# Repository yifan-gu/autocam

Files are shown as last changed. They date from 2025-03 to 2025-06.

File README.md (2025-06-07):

Arduino files for my auto-following camera car!

## TODO
- [x] Add dji remote control and receiver
- [x] <s>Add PID encoder</s> Add a web page for parameters
- [x] Add BLE central for the anchor
- [x] Read joystick values for the remote controller
- [x] Read mode switch button for remote controller
- [x] Add state indicator in the web UI
- [x] Add LED state indicators
- [x] Add battery state LED (tag, remote)
- [x] Add LED logic for tag
- [x] Add lock mode (remote)
- [x] Combine tag and remote
  - [x] Add tag selector (sensor, remote)
- [x] Control the BLE data rate
- [x] Fix UWB Anchor naming, fix AutocamController naming
- [x] Add PCB boards
  - [x] Sensor
  - [x] Verify LED resistor values
  - [x] Verify IO0/IO1 port on the ESP32 UWB is usable 
  - [x] Tag
  - [x] Server
  - [x] Remote
- [x] Smooth the distance measurement.
- [x] Added a different mode (follow).
- [x] Added gimbal recenter and camera recording.
- [x] Assemble together
- [x] Design and make the enclosure
- [ ] Calibrate the UWB tag and anchor
- [ ] Measure battery voltage.
- [ ] (optimize) Store settings in external storage (SD card)
- [x] (optimize) Refactor the server code with a state machine, (Almost a state machine now).
- [ ] (optimize) Refactor the sensor LED control with LED controller
- [ ] (optimize) Reorganize shared code into libraries, add external dependencies 

- [x] heartbeat for the remote controller.
- [ ] <s> Nice to have, detect active track failure</s> Turns out there's no API support for that
- [x] Smart Phone APP for the remote (BLE version).

## KNOWN ISSUES
- [ ] Webserver stabability.
- [x] Steering thread issue (Do not steer before throttle is applied)
- [x] BLE connection issue
- [ ] ESC init issue

<s>- [x] Start/stop recording issue</s> Not actually an issue—I plugged the USB-C cable into the wrong gimbal port. However, since the camera drains the gimbal’s battery, I still remove the cable to conserve power.

- [x] Every time the remote buttons are pressed, send values to the server.

## 🚗 Simulator

👉 [Run the Simulator](https://yifan-gu.github.io/autocam/simulator.html)

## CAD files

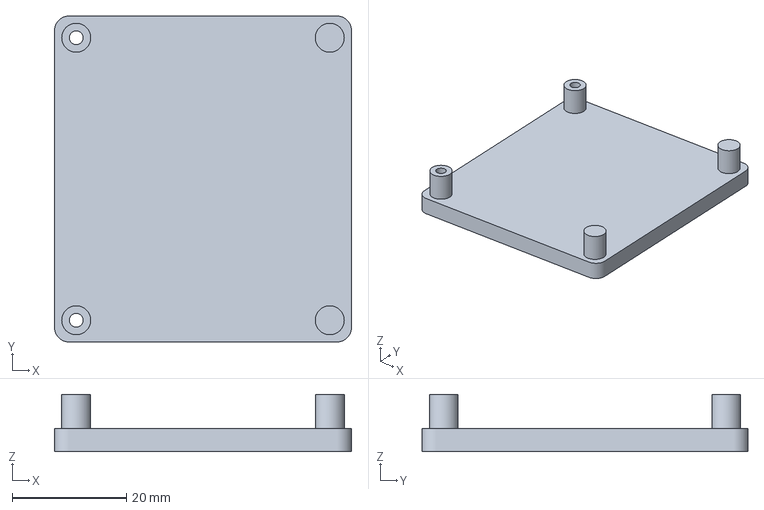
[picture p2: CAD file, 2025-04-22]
hardware/cad/server/Server Base-Base.3mf
52.1 x 57.1 x 10.0 mm

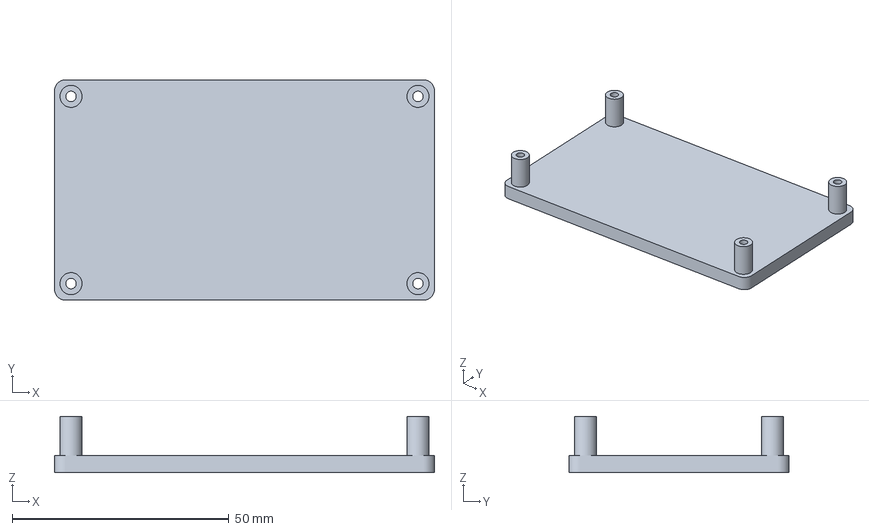
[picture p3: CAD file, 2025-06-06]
hardware/cad/tag/Tag Lid-Lid.3mf
87.6 x 50.8 x 13.0 mm

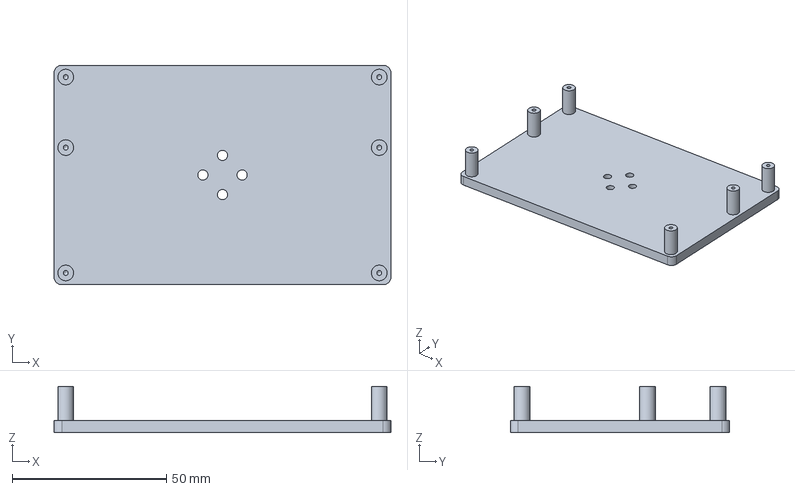
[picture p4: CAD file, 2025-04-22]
hardware/cad/remote/Remote Base.FCStd
109.2 x 71.1 x 15.0 mm

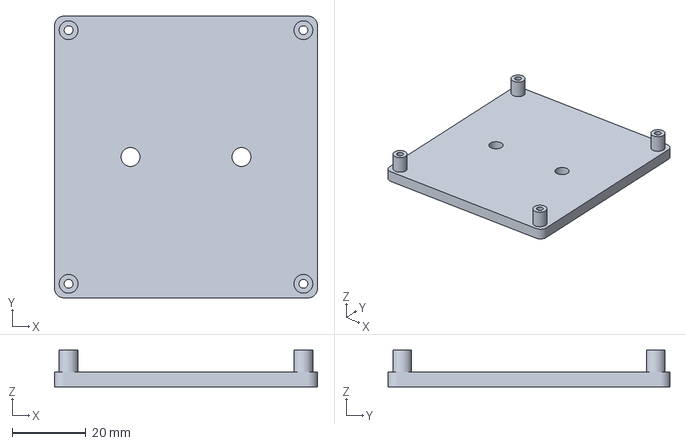
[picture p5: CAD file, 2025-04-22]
hardware/cad/sensor/Sensor Base-Base.3mf
71.1 x 76.2 x 10.0 mm

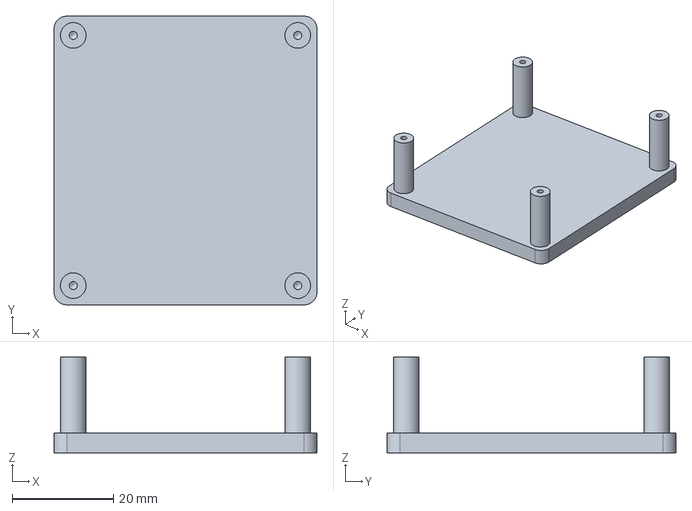
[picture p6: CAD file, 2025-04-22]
hardware/cad/server/Server Lid.FCStd
52.1 x 57.1 x 19.0 mm

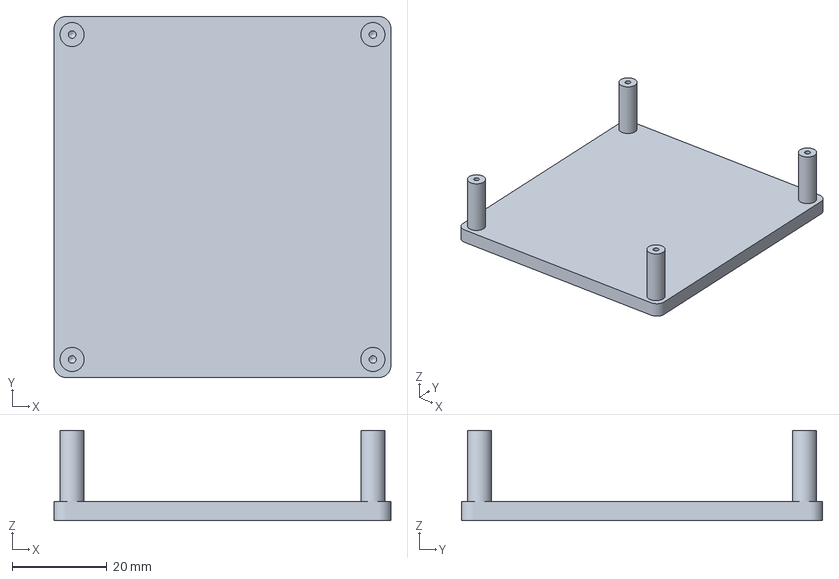
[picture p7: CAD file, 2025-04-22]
hardware/cad/sensor/Sensor Lid-Lid.3mf
71.1 x 76.2 x 19.0 mm

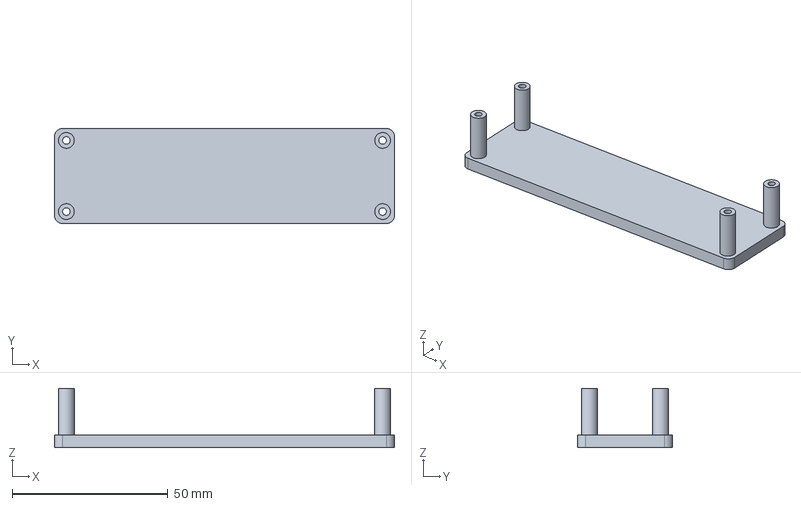
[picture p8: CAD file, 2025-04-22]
hardware/cad/remote/Remote Lid.FCStd
109.2 x 30.5 x 19.0 mm

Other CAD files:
hardware/cad/remote/Remote Assembly.FCStd
hardware/cad/sensor/Sensor Assembly.FCStd
hardware/cad/tag/Tag Assembly.FCStd
hardware/cad/server/Server Assembly.FCStd
hardware/cad/tag/Tag Base.FCStd
hardware/cad/remote/Remote Base-Base.3mf
hardware/cad/server/Server Base.FCStd
hardware/cad/tag/Tag Lid.FCStd
hardware/cad/sensor/Sensor Base.FCStd
hardware/cad/server/Server Lid-Lid.3mf
hardware/cad/remote/Remote Lid-Lid.3mf
hardware/cad/sensor/Sensor Lid.FCStd
hardware/cad/tag/Tag Base-Base.3mf

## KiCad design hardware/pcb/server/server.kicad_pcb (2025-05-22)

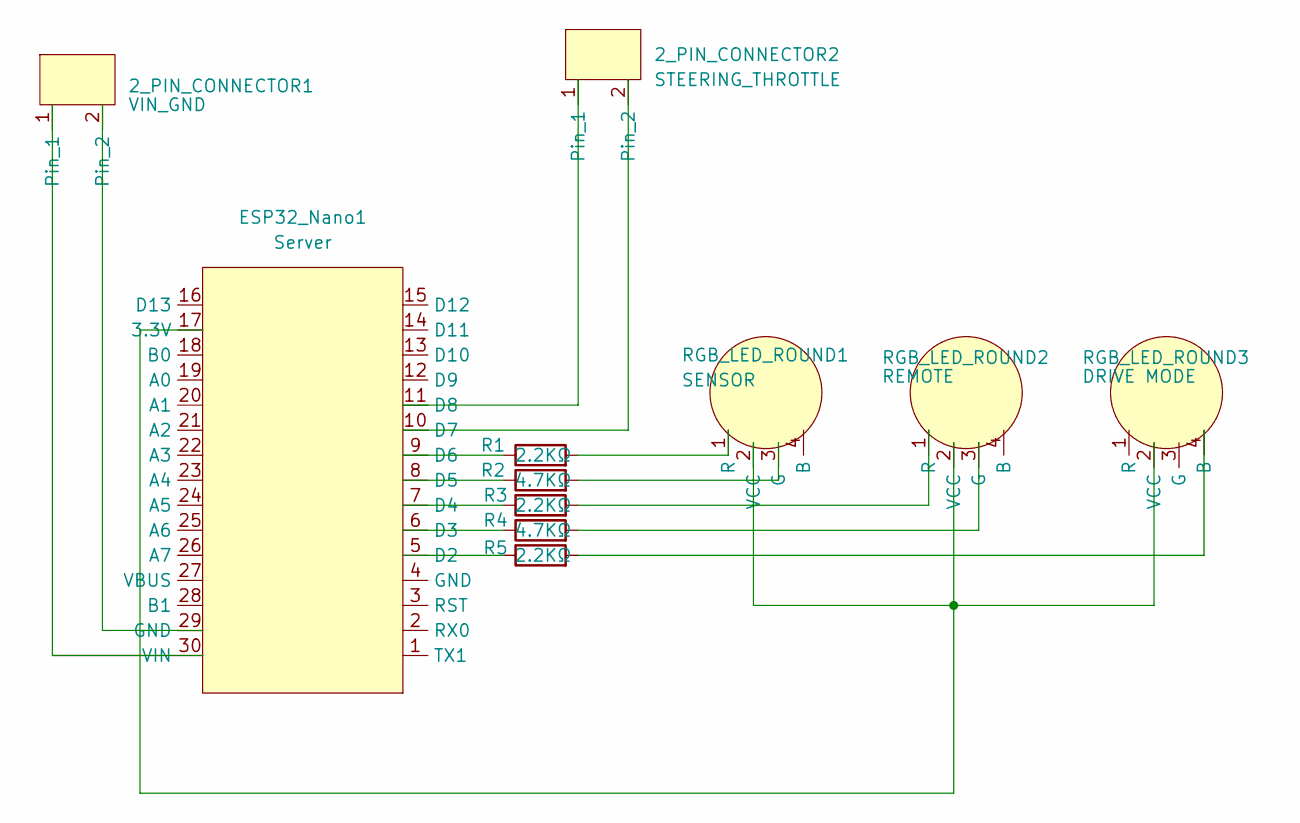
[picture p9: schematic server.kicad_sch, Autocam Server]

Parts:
2_PIN_CONNECTOR1: VIN_GND; 2-PIN Connector
2_PIN_CONNECTOR2: STEERING_THROTTLE; 2-PIN Connector
ESP32_Nano1: Server; Arduino ESP32 Nano
R1, R3, R5: 2.2KΩ; Simple Resistor
R2, R4: 4.7KΩ; Simple Resistor
RGB_LED_ROUND1: SENSOR; Anode RGB LED (Round)
RGB_LED_ROUND2: REMOTE; Anode RGB LED (Round)
RGB_LED_ROUND3: DRIVE MODE; Anode RGB LED (Round)

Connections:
unnamed: 2_PIN_CONNECTOR1.1, ESP32_Nano1.30 (VIN)
unnamed: 2_PIN_CONNECTOR1.2, ESP32_Nano1.29 (GND)
unnamed: 2_PIN_CONNECTOR2.1, ESP32_Nano1.11 (D8)
unnamed: 2_PIN_CONNECTOR2.2, ESP32_Nano1.10 (D7)
unnamed: ESP32_Nano1.17 (3.3V), RGB_LED_ROUND1.2 (VCC), RGB_LED_ROUND2.2 (VCC), RGB_LED_ROUND3.2 (VCC)
unnamed: ESP32_Nano1.5 (D2), R5.1
unnamed: ESP32_Nano1.6 (D3), R4.1
unnamed: ESP32_Nano1.7 (D4), R3.1
unnamed: ESP32_Nano1.8 (D5), R2.1
unnamed: ESP32_Nano1.9 (D6), R1.1
unnamed: R2.2, RGB_LED_ROUND1.3 (G)
unnamed: R1.2, RGB_LED_ROUND1.1 (R)
unnamed: R4.2, RGB_LED_ROUND2.3 (G)
unnamed: R3.2, RGB_LED_ROUND2.1 (R)
unnamed: R5.2, RGB_LED_ROUND3.4 (B)

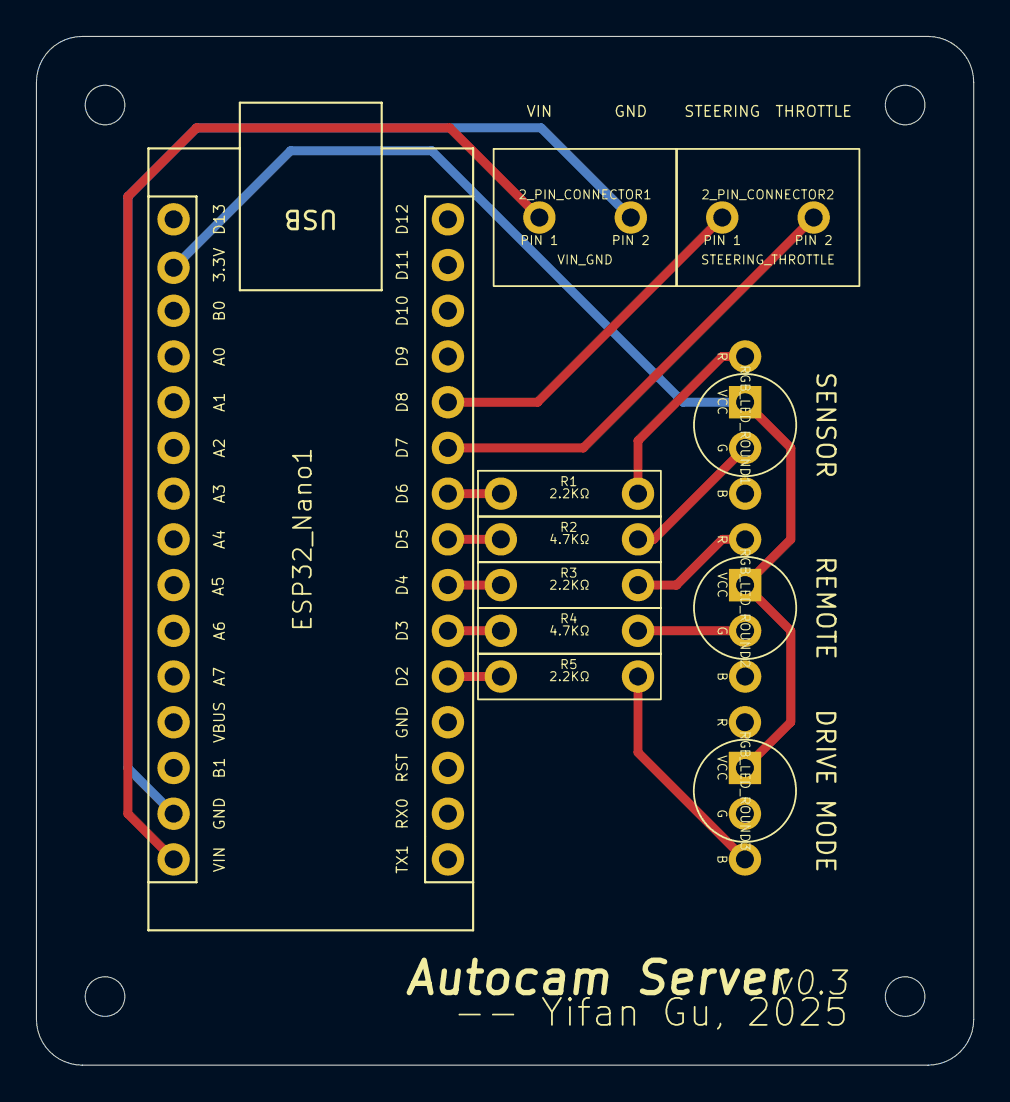
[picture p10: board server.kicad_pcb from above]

Board: 2 copper layers, 52.1 x 57.2 mm, 11 parts (0 on the bottom side), 15 nets.

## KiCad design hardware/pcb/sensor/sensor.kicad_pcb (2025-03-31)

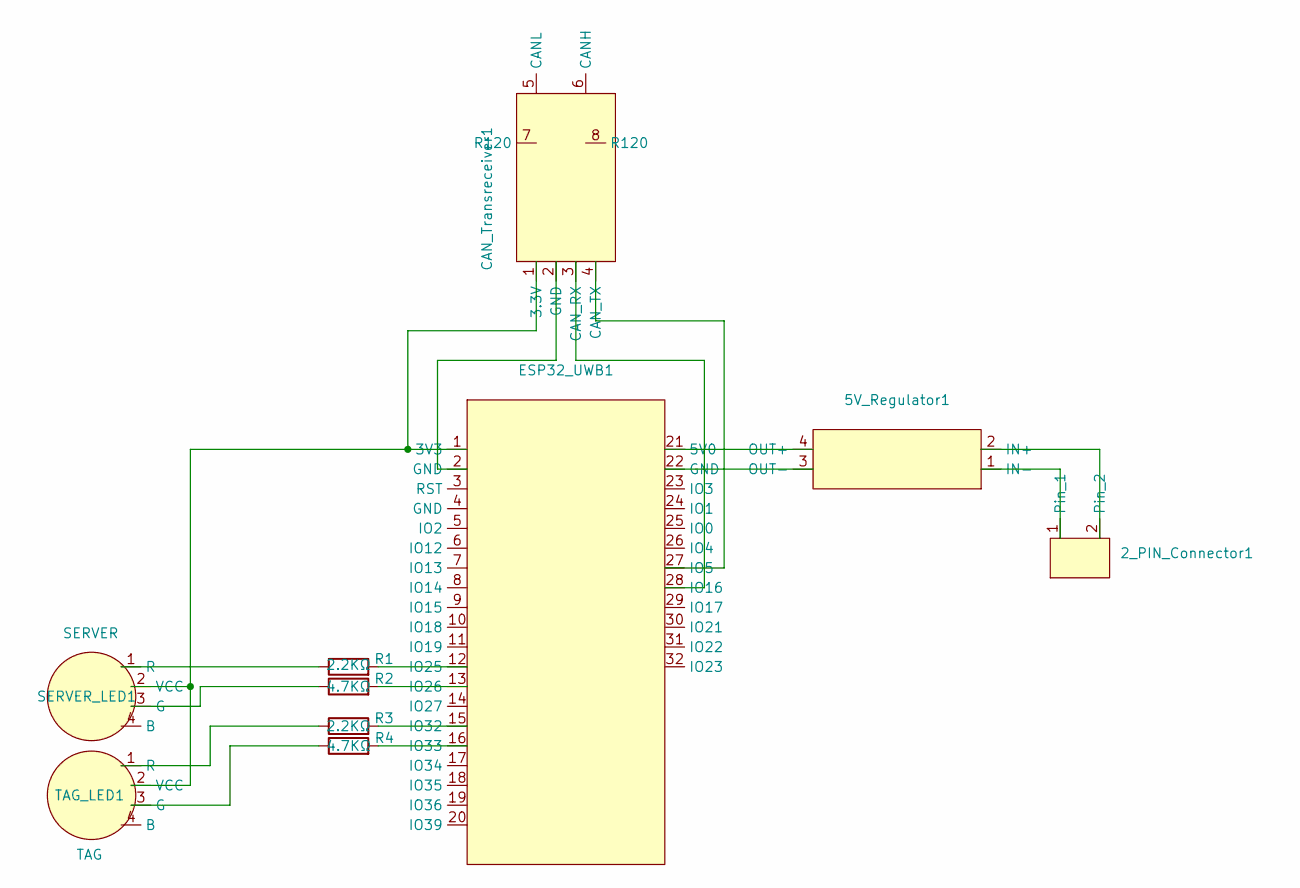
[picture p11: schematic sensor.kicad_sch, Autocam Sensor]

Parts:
2_PIN_Connector1: 2-PIN Connector
5V_Regulator1: MP1584EN 5V Regulator
CAN_Transreceiver1: Waveshare CAN Transreceiver
ESP32_UWB1: Makersfab ESP32 UWB
R1, R3: 2.2KΩ; Simple Resistor
R2, R4: 4.7KΩ; Simple Resistor
SERVER_LED1: SERVER; Anode RGB LED (Round)
TAG_LED1: TAG; Anode RGB LED (Round)

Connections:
unnamed: 2_PIN_Connector1.1, 5V_Regulator1.1 (IN-)
unnamed: 2_PIN_Connector1.2, 5V_Regulator1.2 (IN+)
unnamed: 5V_Regulator1.4 (OUT+), ESP32_UWB1.21 (5V0)
unnamed: 5V_Regulator1.3 (OUT-), ESP32_UWB1.22 (GND)
unnamed: CAN_Transreceiver1.1 (3.3V), ESP32_UWB1.1 (3V3), SERVER_LED1.2 (VCC), TAG_LED1.2 (VCC)
unnamed: CAN_Transreceiver1.3 (CAN_RX), ESP32_UWB1.28 (IO16)
unnamed: CAN_Transreceiver1.4 (CAN_TX), ESP32_UWB1.27 (IO5)
unnamed: CAN_Transreceiver1.2 (GND), ESP32_UWB1.2 (GND)
unnamed: ESP32_UWB1.12 (IO25), R1.2
unnamed: ESP32_UWB1.13 (IO26), R2.2
unnamed: ESP32_UWB1.15 (IO32), R3.2
unnamed: ESP32_UWB1.16 (IO33), R4.2
unnamed: R2.1, SERVER_LED1.3 (G)
unnamed: R1.1, SERVER_LED1.1 (R)
unnamed: R4.1, TAG_LED1.3 (G)
unnamed: R3.1, TAG_LED1.1 (R)

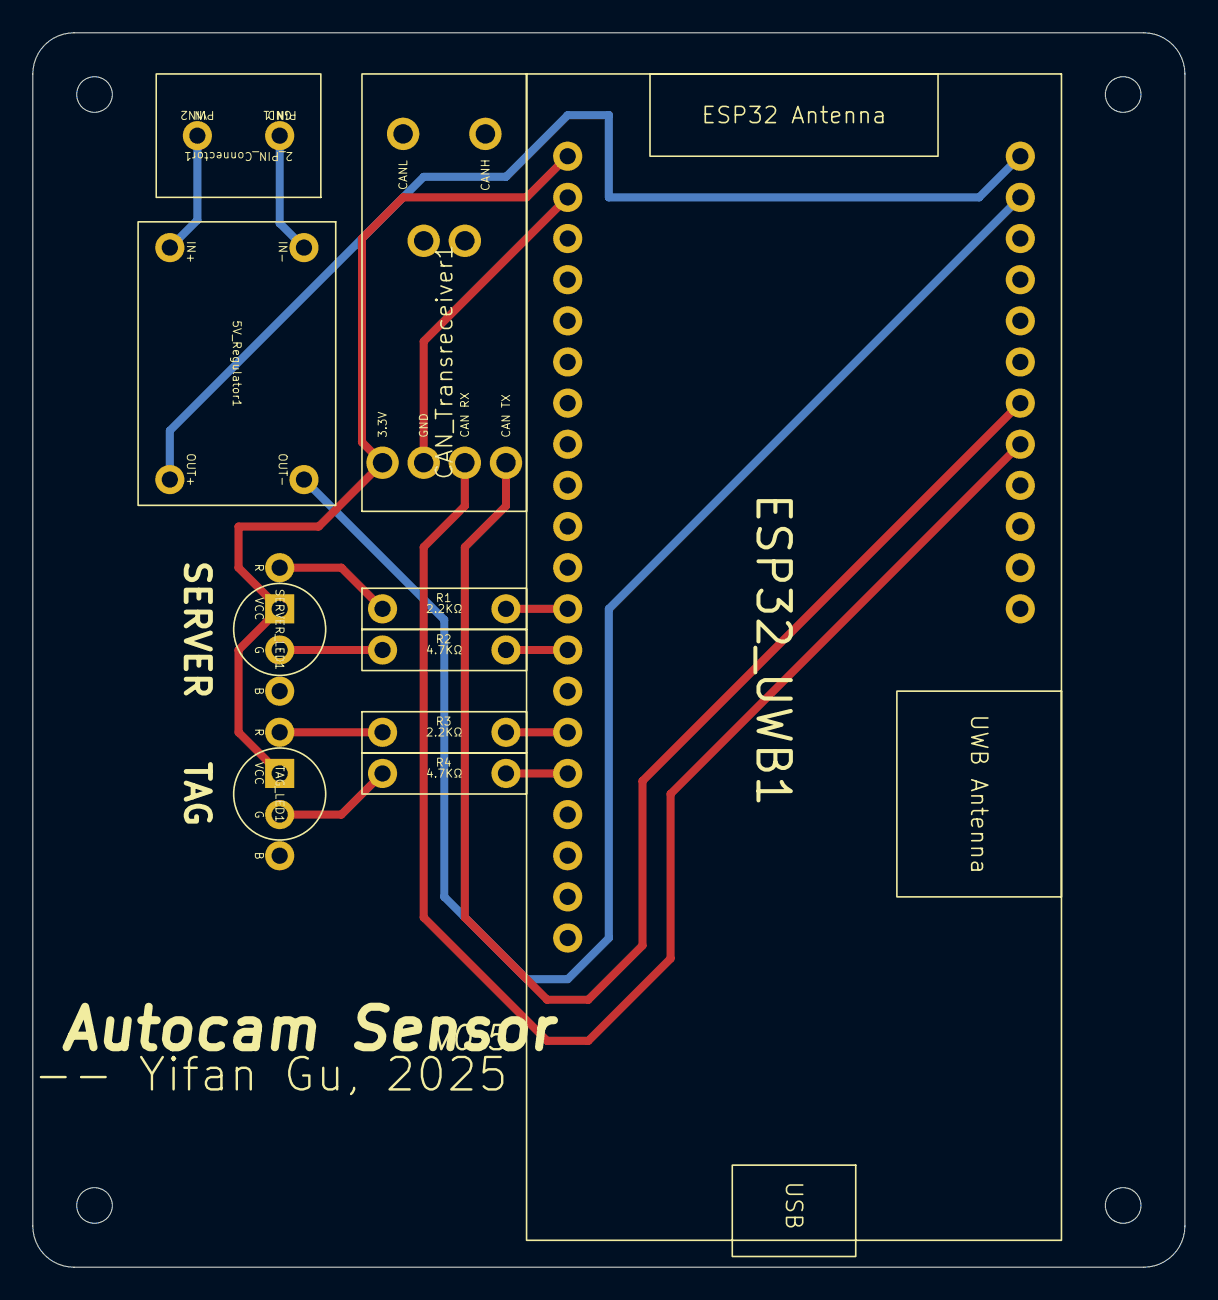
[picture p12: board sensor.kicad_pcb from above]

Board: 2 copper layers, 71.1 x 76.2 mm, 10 parts (0 on the bottom side), 16 nets.

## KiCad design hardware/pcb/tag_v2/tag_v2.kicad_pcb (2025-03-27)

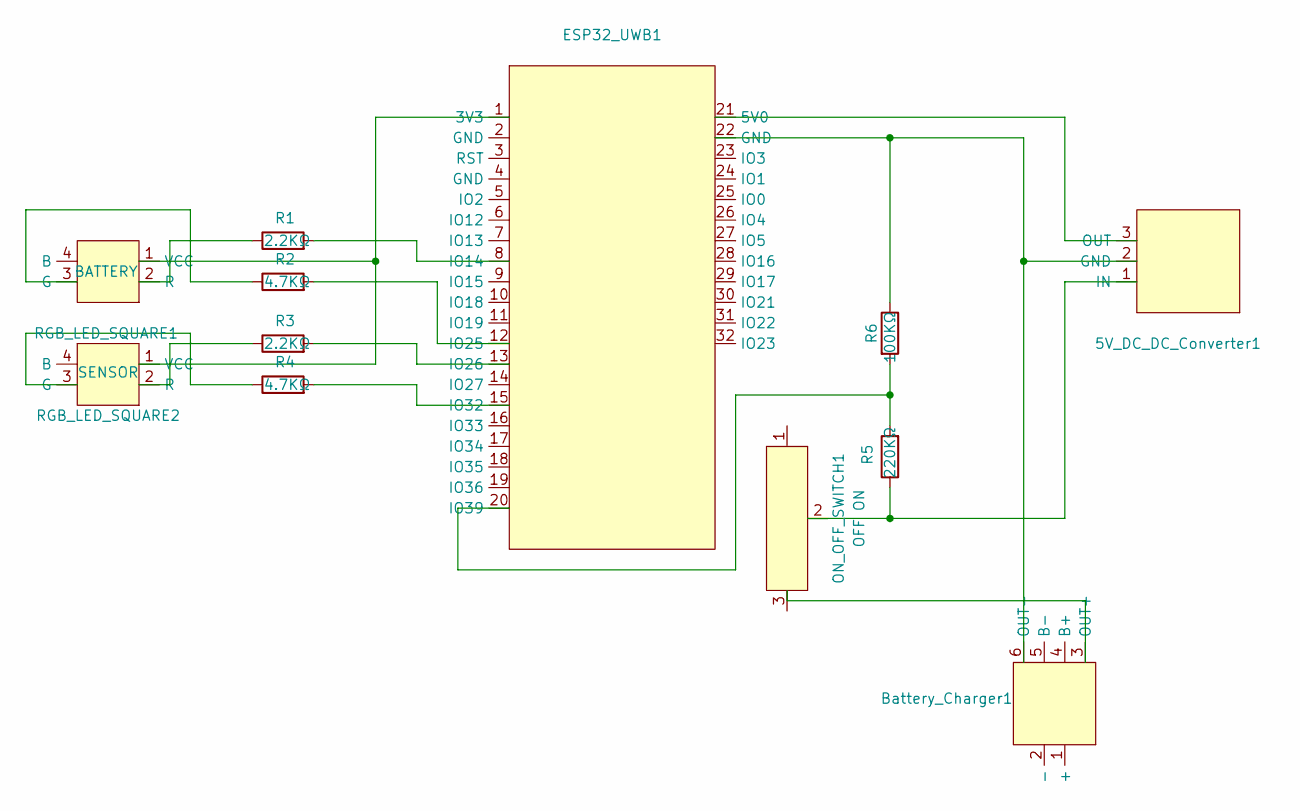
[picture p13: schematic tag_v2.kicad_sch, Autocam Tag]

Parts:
5V_DC_DC_Converter1: 5V DC-DC Step Up Converter (Square)
Battery_Charger1: USB-C 3.7V Lithium Battery Charger
ESP32_UWB1: Makersfab ESP32 UWB
ON_OFF_SWITCH1: OFF ON; 3-PIN Switch
R1, R3: 2.2KΩ; Simple Resistor
R2, R4: 4.7KΩ; Simple Resistor
R5: 220KΩ; Simple Resistor
R6: 100KΩ; Simple Resistor
RGB_LED_SQUARE1: BATTERY; Anode RGB LED (Square)
RGB_LED_SQUARE2: SENSOR; Anode RGB LED (Square)

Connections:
unnamed: 5V_DC_DC_Converter1.2 (GND), Battery_Charger1.6 (OUT-), ESP32_UWB1.22 (GND), R6.1
unnamed: 5V_DC_DC_Converter1.1 (IN), ON_OFF_SWITCH1.2, R5.1
unnamed: 5V_DC_DC_Converter1.3 (OUT), ESP32_UWB1.21 (5V0)
unnamed: Battery_Charger1.3 (OUT+), ON_OFF_SWITCH1.3
unnamed: ESP32_UWB1.1 (3V3), RGB_LED_SQUARE1.1 (VCC), RGB_LED_SQUARE2.1 (VCC)
unnamed: ESP32_UWB1.8 (IO14), R1.2
unnamed: ESP32_UWB1.12 (IO25), R2.2
unnamed: ESP32_UWB1.13 (IO26), R3.2
unnamed: ESP32_UWB1.15 (IO32), R4.2
unnamed: ESP32_UWB1.20 (IO39), R5.2, R6.2
unnamed: R2.1, RGB_LED_SQUARE1.3 (G)
unnamed: R1.1, RGB_LED_SQUARE1.2 (R)
unnamed: R4.1, RGB_LED_SQUARE2.3 (G)
unnamed: R3.1, RGB_LED_SQUARE2.2 (R)

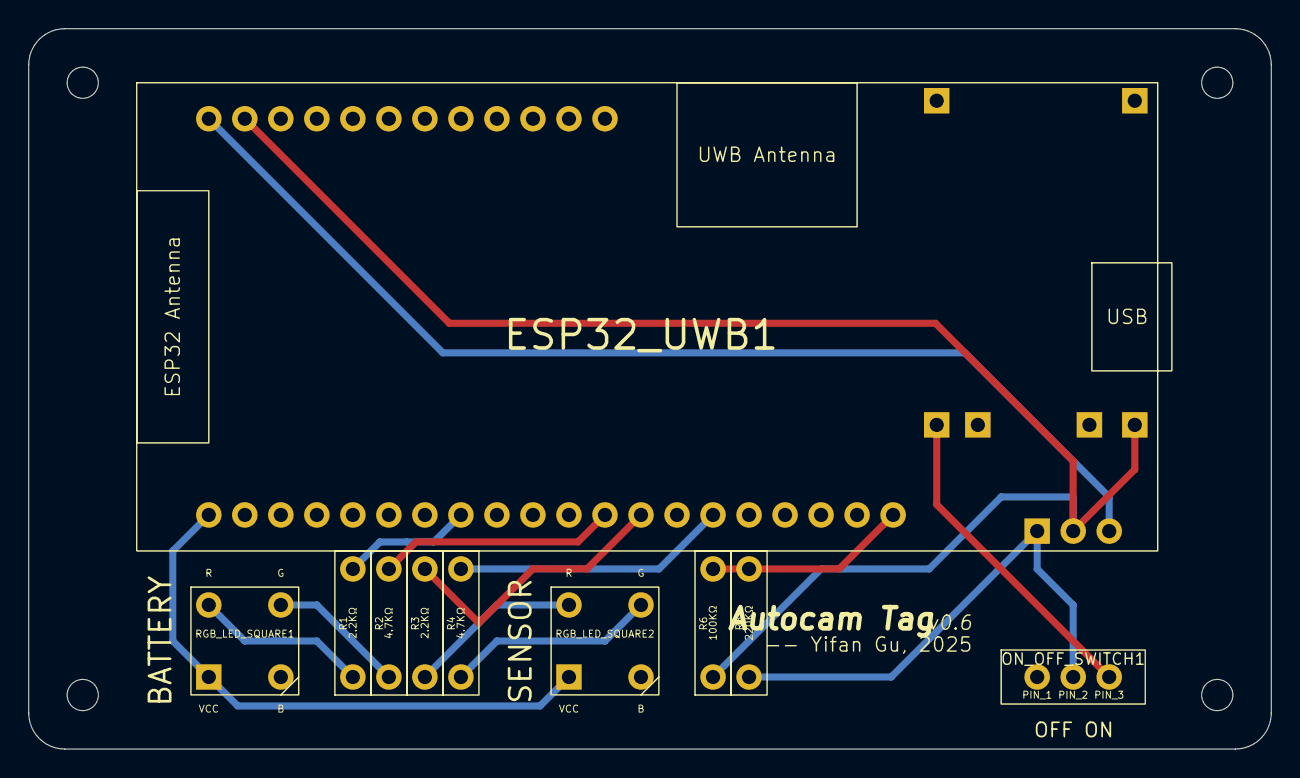
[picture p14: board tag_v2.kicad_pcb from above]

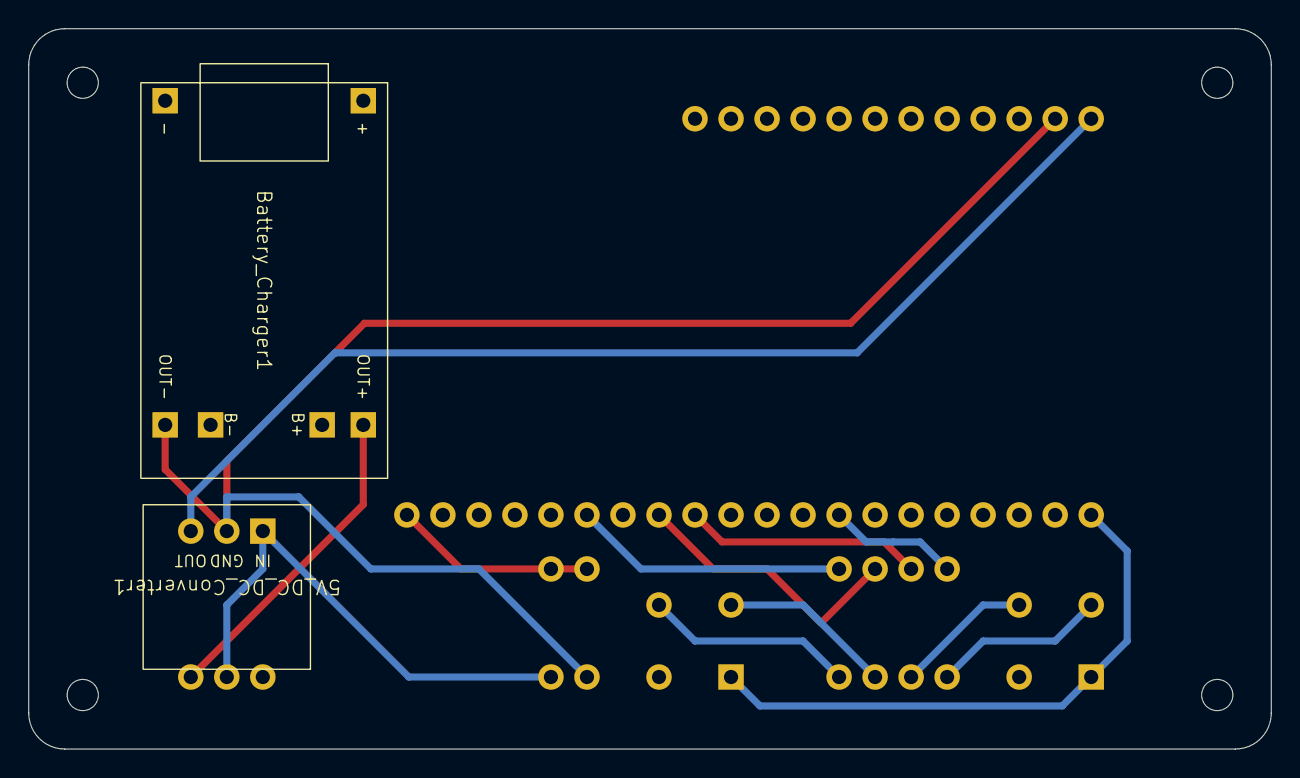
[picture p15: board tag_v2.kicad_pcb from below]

Board: 2 copper layers, 87.6 x 50.8 mm, 12 parts (2 on the bottom side), 14 nets.

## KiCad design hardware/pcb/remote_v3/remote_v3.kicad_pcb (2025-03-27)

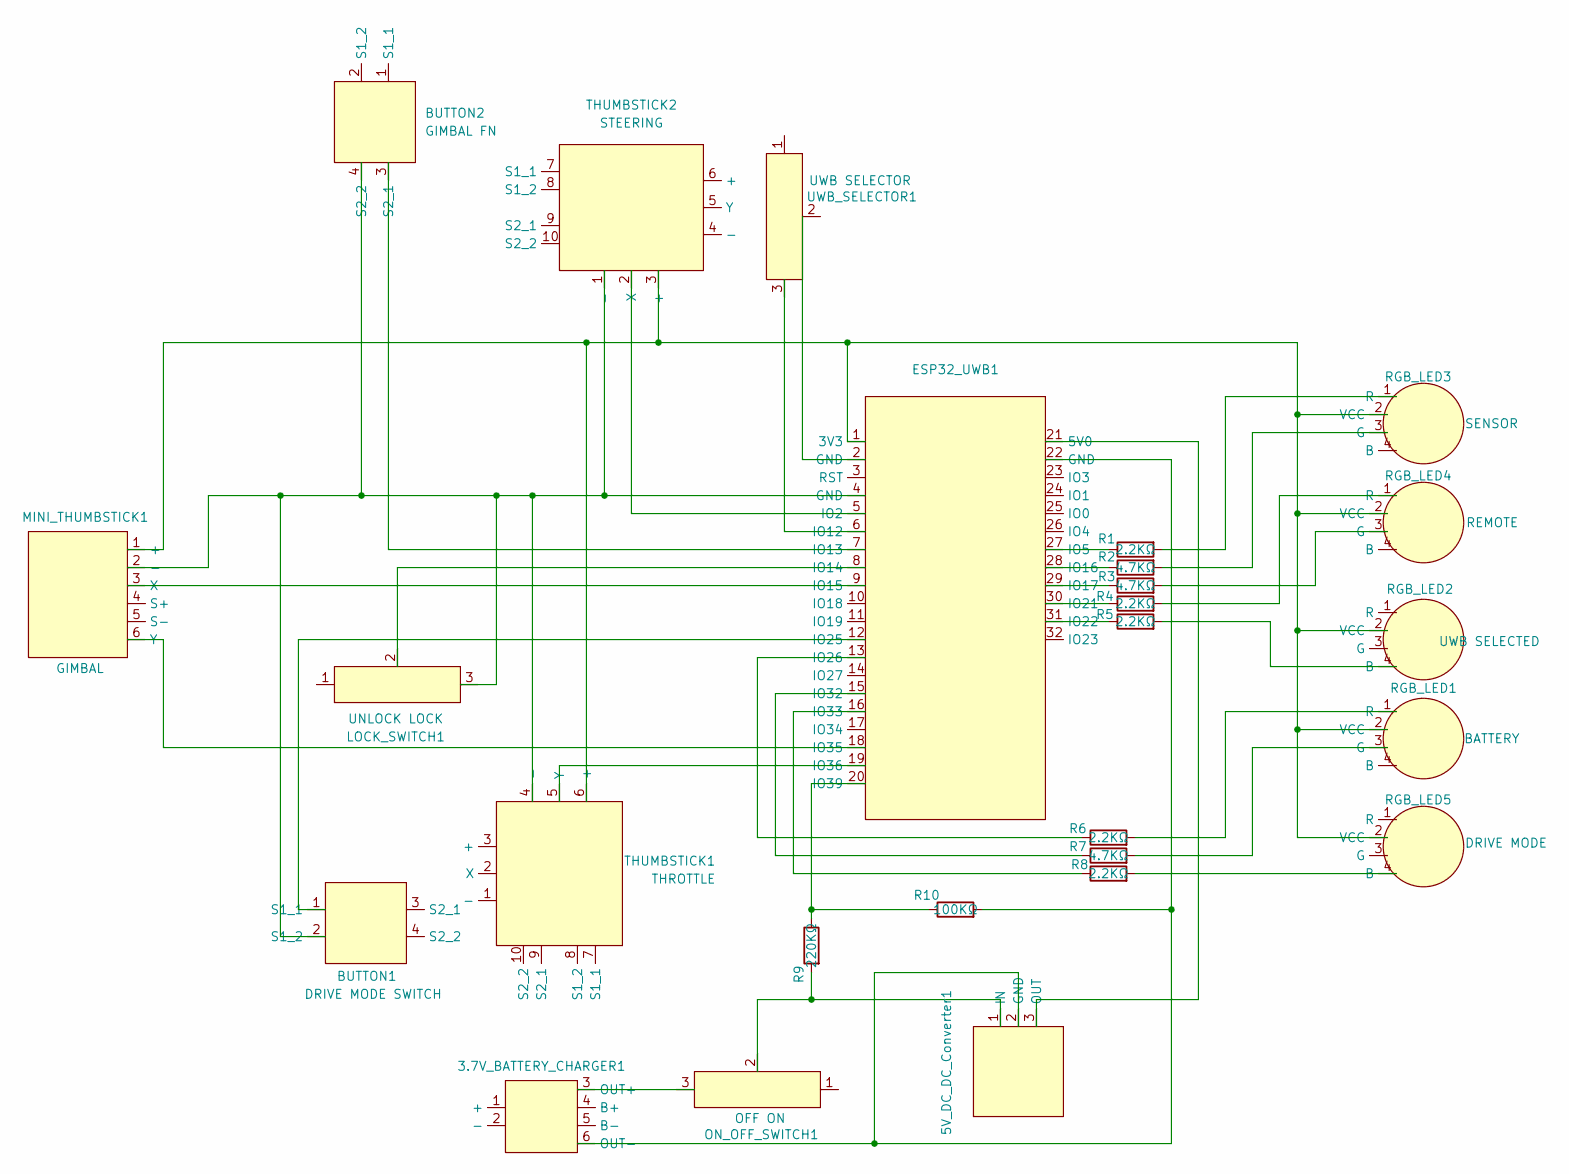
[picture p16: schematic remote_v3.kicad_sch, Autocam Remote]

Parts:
3.7V_BATTERY_CHARGER1: USB-C 3.7V Lithium Battery Charger
5V_DC_DC_Converter1: 5V DC-DC Step Up Converter (Square)
BUTTON1: DRIVE MODE SWITCH; Tactile Switch Button (Square)
BUTTON2: GIMBAL FN; Tactile Switch Button (Square)
ESP32_UWB1: Makersfab ESP32 UWB
LOCK_SWITCH1: UNLOCK LOCK; 3-PIN Switch
MINI_THUMBSTICK1: GIMBAL; Mini Analog Joystick
ON_OFF_SWITCH1: OFF ON; 3-PIN Switch
R1, R4, R5, R6, R8: 2.2KΩ; Simple Resistor
R2, R3, R7: 4.7KΩ; Simple Resistor
R9: 220KΩ; Simple Resistor
R10: 100KΩ; Simple Resistor
RGB_LED1: BATTERY; Anode RGB LED (Round)
RGB_LED2: UWB SELECTED; Anode RGB LED (Round)
RGB_LED3: SENSOR; Anode RGB LED (Round)
RGB_LED4: REMOTE; Anode RGB LED (Round)
RGB_LED5: DRIVE MODE; Anode RGB LED (Round)
THUMBSTICK1: THROTTLE; X-Box Style Thumbstick
THUMBSTICK2: STEERING; X-Box Style Thumbstick
UWB_SELECTOR1: UWB SELECTOR; 3-PIN Switch

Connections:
unnamed: 3.7V_BATTERY_CHARGER1.3 (OUT+), ON_OFF_SWITCH1.3
unnamed: 3.7V_BATTERY_CHARGER1.6 (OUT-), 5V_DC_DC_Converter1.2 (GND), ESP32_UWB1.22 (GND), R10.2
unnamed: 5V_DC_DC_Converter1.1 (IN), ON_OFF_SWITCH1.2, R9.2
unnamed: 5V_DC_DC_Converter1.3 (OUT), ESP32_UWB1.21 (5V0)
unnamed: BUTTON1.1 (S1), ESP32_UWB1.12 (IO25)
unnamed: BUTTON1.2 (S1), BUTTON2.4 (S2_2), ESP32_UWB1.4 (GND), LOCK_SWITCH1.3, MINI_THUMBSTICK1.2 (-), THUMBSTICK1.4 (-), THUMBSTICK2.1 (-)
unnamed: BUTTON2.3 (S2_1), ESP32_UWB1.7 (IO13)
unnamed: ESP32_UWB1.1 (3V3), MINI_THUMBSTICK1.1 (+), RGB_LED1.2 (VCC), RGB_LED2.2 (VCC), RGB_LED3.2 (VCC), RGB_LED4.2 (VCC), RGB_LED5.2 (VCC), THUMBSTICK1.6 (+), THUMBSTICK2.3 (+)
unnamed: ESP32_UWB1.2 (GND), UWB_SELECTOR1.2
unnamed: ESP32_UWB1.5 (IO2), THUMBSTICK2.2 (X)
unnamed: ESP32_UWB1.27 (IO5), R1.1
unnamed: ESP32_UWB1.6 (IO12), UWB_SELECTOR1.3
unnamed: ESP32_UWB1.8 (IO14), LOCK_SWITCH1.2
unnamed: ESP32_UWB1.9 (IO15), MINI_THUMBSTICK1.3 (X)
unnamed: ESP32_UWB1.28 (IO16), R2.1
unnamed: ESP32_UWB1.29 (IO17), R3.1
unnamed: ESP32_UWB1.30 (IO21), R4.1
unnamed: ESP32_UWB1.31 (IO22), R5.1
unnamed: ESP32_UWB1.13 (IO26), R6.1
unnamed: ESP32_UWB1.15 (IO32), R7.1
unnamed: ESP32_UWB1.16 (IO33), R8.1
unnamed: ESP32_UWB1.18 (IO35), MINI_THUMBSTICK1.6 (Y)
unnamed: ESP32_UWB1.19 (IO36), THUMBSTICK1.5 (Y)
unnamed: ESP32_UWB1.20 (IO39), R9.1, R10.1
unnamed: R7.2, RGB_LED1.3 (G)
unnamed: R6.2, RGB_LED1.1 (R)
unnamed: R5.2, RGB_LED2.4 (B)
unnamed: R2.2, RGB_LED3.3 (G)
unnamed: R1.2, RGB_LED3.1 (R)
unnamed: R3.2, RGB_LED4.3 (G)
unnamed: R4.2, RGB_LED4.1 (R)
unnamed: R8.2, RGB_LED5.4 (B)

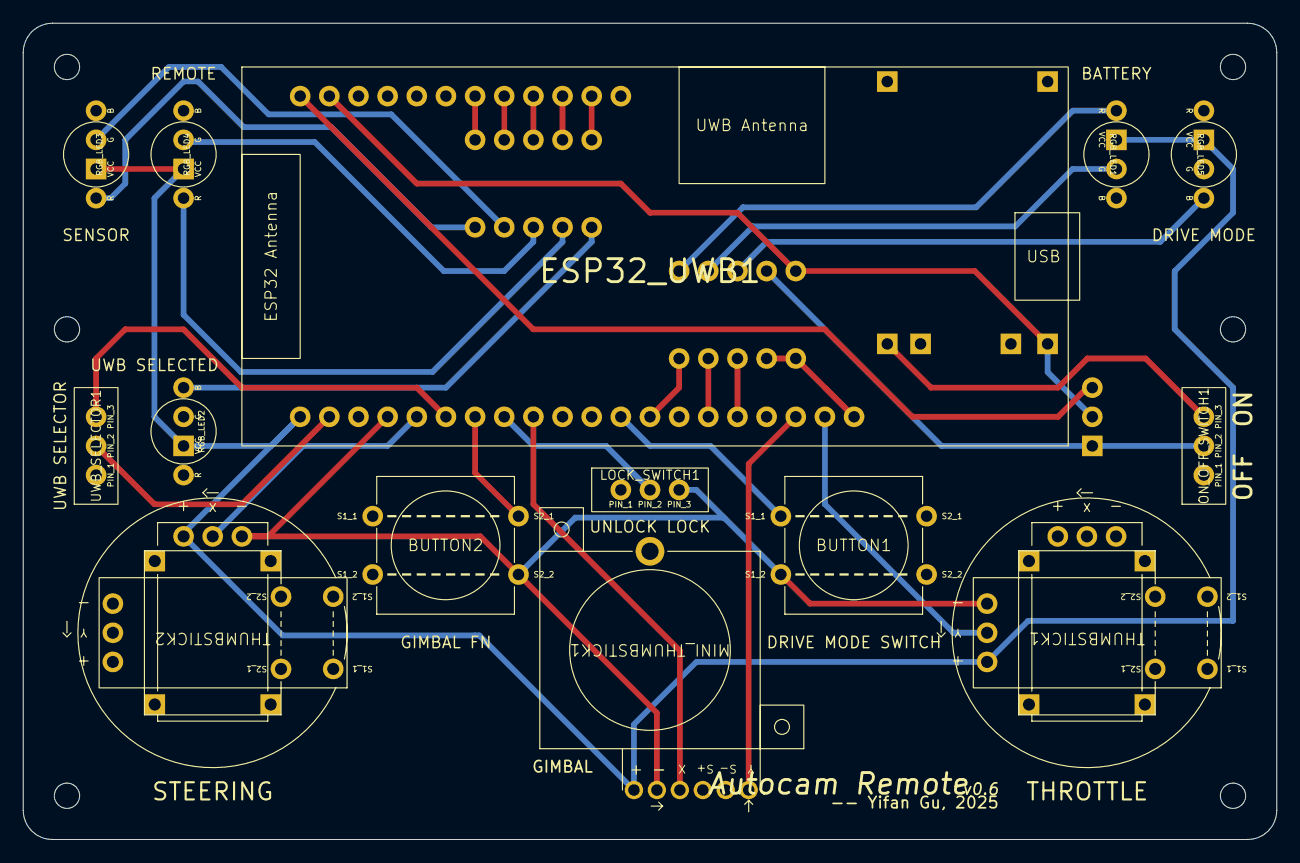
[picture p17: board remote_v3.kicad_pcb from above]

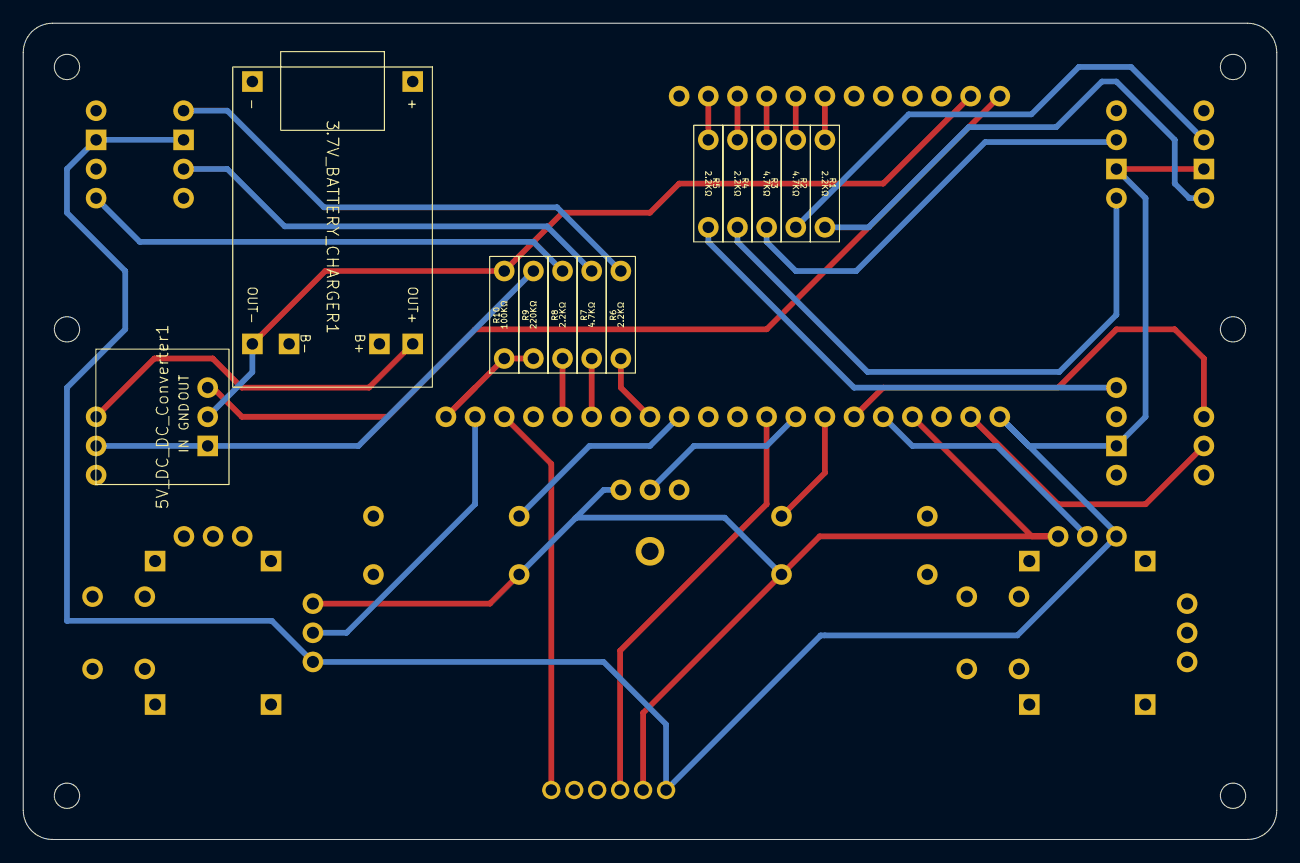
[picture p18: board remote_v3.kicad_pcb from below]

Board: 2 copper layers, 109.2 x 71.1 mm, 26 parts (12 on the bottom side), 32 nets.

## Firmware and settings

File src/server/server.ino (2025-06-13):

#include <ESPAsyncWebServer.h>
#include <ESPmDNS.h>
#include <math.h>
#include <WiFi.h>

#include "html_pages.h"
#include "BLE_setup.hpp"
#include "LED_controller.hpp"
#include "util.h"

// Use 50Hz for servos/ESCs, 12-bit resolution
#define PWM_FREQ 50
#define PWM_RESOLUTION 12  // 12-bit (0–4095)

// ESC output PWM channels
#define THROTTLE_PWM_CHANNEL 0
#define STEERING_PWM_CHANNEL 1

// Pin configuration
#define STEERING_PIN A6  //  A6 for steering
#define THROTTLE_PIN A5  //  A5 for throttle

#define SENSOR_LED_RED_PIN A4 // A4
#define SENSOR_LED_GREEN_PIN A3 // A3
#define SENSOR_LED_BLUE_PIN -1

#define REMOTE_LED_RED_PIN A2 // A2
#define REMOTE_LED_GREEN_PIN A1 // A1
#define REMOTE_LED_BLUE_PIN -1

#define DRIVE_MODE_LED_RED_PIN -1
#define DRIVE_MODE_LED_GREEN_PIN -1
#define DRIVE_MODE_LED_BLUE_PIN A0 // A0

LEDController ledController;

// Access Point credentials
const char* ssid = "Autocam Server";
const char* password = "AbsoluteCinema!"; // Minimum 8 characters
const char* hostname = "autocam"; // mDNS hostname

// Async WebSocket server
AsyncWebServer server(80);
AsyncWebSocket ws("/ws");

// A small buffer to hold incoming fragments
static String wsBuffer;

// Define throttle and steering ranges
const int16_t minThrottle = 1000, maxThrottle = 2000, midThrottle = 1500;
const int16_t minSteering = 1000, maxSteering = 2000, midSteering = 1500; // 1000 = max right turn, 2000 = max left turn.
const int16_t minSteeringThrottle = 50;

const float fieldOfViewRatio = 28 / 20; // Car length / car width (measured from the wheel).
const float SAFETY_DISTANCE = 10.0; // Maximum distance allowed, if current distance goes beyond this value, the car will stop.

int16_t minMoveThrottle = 1100, maxMoveThrottle = 1900;
int16_t minMoveSteering = 1000, maxMoveSteering = 2000;

// Heartbeat tracking
unsigned long lastWebSocketDataMillis = 0;

unsigned long lastSensorConnectedTime = 0;
unsigned long lastSensorDataMillis = 0;

unsigned long lastRemoteConnectedTime = 0;
unsigned long lastRemoteDataMillis = 0;
unsigned long lastRemoteStatusUpdatedMillis = 0;

const unsigned long sensorHeartbeatTimeout = 2000; // 2 seconds timeout to tolerate CAN communication failure.
const unsigned long remoteHeartbeatTimeout = 3000; // 3 seconds timeout
const unsigned long CONNECT_GRACE_MS = 2000; // 2000ms grace after BLE_CONNECTED
const unsigned long remoteStatusUpdateDuration = 400; // Update the remote's status every 400ms to keep the iOS app awake in the background even when the screen is locked.

struct GlobalState {
  int16_t throttleValue;       // e.g., servo pulse width for throttle
  int16_t steeringValue;       // e.g., servo pulse width for steering
  uint8_t state;               // overall state (e.g., SERVER_STATE_NOT_READY, etc.)
  uint8_t driveMode;           // e.g., DRIVE_MODE_MANUAL, DRIVE_MODE_FOLLOW, DRIVE_MODE_CINEMA
  float distance;          // distance from the Tag/Remote to the Sensor
  float targetDistance;    // desired distance
  float heading;           // measured heading in degrees [0, 360)  Front = 0/360, Left = 90, Back = 180, Right = 270
  float targetHeading;     // desired heading in degrees
  float yawSpeed;          // Yaw speed
  float pitchSpeed;        // Pitch speed
  uint8_t toggleState;         // Flag to store all the toggle button value (activeTrack, gimbalRecenter, cameraRecording)
  uint8_t uwbSelector;    // UWB selector value
  float currentX;          // The tag's current coordinates.
  float currentY;          // The tag's current coordinates.
  float targetX;           // The tag's target coordinates.
  float targetY;           // The tag's target coordinates.
};

GlobalState globalState = {
  midThrottle,           // throttleValue
  midSteering,           // steeringValue
  SERVER_STATE_NOT_READY,       // state
  DRIVE_MODE_MANUAL,     // driveMode
  0.0,                   // distance
  0.0,                   // targetDistance
  0.0,                   // heading
  0.0,                   // targetHeading
  0.0,                   // yawSpeed
  0.0,                   // pitchSpeed
  0,                     // toggleState
  0,                     // uwbSelector
  0.0,                   // currentX
  0.0,                   // currentY
  0.0,                   // targetX
  0.0,                   // targetY
};

void printGlobalState() {
  LOGF("Throttle:%d, Steering:%d, State:%d, Drive Mode:%d, Dist:%.2f, TargetDist:%.2f, Head:%.2f, TargetHead:%.2f, Yaw:%.2f, Pitch:%.2f, toggleState:%d, UWB Selector:%d, currentX: %.2f, currentY: %.2f, targetX: %.2f, targetY: %.2f\n",
    globalState.throttleValue,
    globalState.steeringValue,
    globalState.state,
    globalState.driveMode,
    globalState.distance,
    globalState.targetDistance,
    globalState.heading,
    globalState.targetHeading,
    globalState.yawSpeed,
    globalState.pitchSpeed,
    globalState.toggleState,
    globalState.uwbSelector,
    globalState.currentX,
    globalState.currentY,
    globalState.targetX,
    globalState.targetY
  );
}

bool autocamRemoteDataUpdated = false;

enum BleConnectState {
  BLE_IDLE = 0,
  BLE_SCANNING,   // Actively trying to discover “Send” and/or “Recv”
  BLE_CONNECTED   // Both characteristics discovered
};

// For Remote:
BleConnectState remoteState       = BLE_IDLE;
bool            remoteSendReady   = false;
bool            remoteRecvReady   = false;

// For Sensor:
BleConnectState sensorState       = BLE_IDLE;
bool            sensorSendReady   = false;
bool            sensorRecvReady   = false;

// For Websocket:
enum WebSocketState {
  WEBSOCKET_DISCONNECTED = 0,
  WEBSOCKET_CONNECTED,
};

WebSocketState wsState = WEBSOCKET_DISCONNECTED;

//////////////////////////////////////////////////////////////////////////////////
//
// PID Controller variables for throttle. Tunable.
//
float distanceDelta = 0.0; // The distance tolerance in meters.
float headingDelta = 0; // The heading tolerance in degrees.
float cinemaLeadingHeadingDelta = 0; // The heading tolerance in cinema leading in meters (converts xDiff to headingDiff);
float throttleConstant = 100;
float steeringConstant = 10;

float Kp_t = 1.5;  // Proportional gain. Diff = Kp_t * distance
float Ki_t = 4;  // Integral gain. Diff = Ki_t * distance * 1000 * second, Ki_t * maxIntegralLimit_t * throttleConstant = IntegramThrottle
float Kd_t = 0.5;  // Derivative gain. Diff = Kd_t / (speed m/s * 1000 ms)

float previousError_t = 0.0;  // Previous error for the derivative term
float integral_t = 0.0;       // Accumulated integral term
float maxIntegralLimit_t = 0.25; // Ki_t * maxIntegralLimit_t * throttleConstant = IntegramThrottle
float maxIntegralLimit_s = 0;

// // PID Controller variables for steering.
float Kp_s = 1.0;   // Proportional gain. Diff = Kp_s * angle diff.
float Ki_s = 0.0;  // Integral gain. Diff = Ki_s * angle diff * 1000 * second.
float Kd_s = 0.0;   // Derivative gain. Diff = Kd_s / (anglur speed * 1000 ms)

float previousError_s = 0.0;  // Previous error for the derivative term
float integral_s = 0.0;       // Accumulated integral term

float lastDeltaTimeMillis = 0; // Used to calculate ki, and Kd in the PID system.
float minDeltaTimeMillis = 10; // Control the rate of PID update.
float deltaTimeThreshold = 1000; // If the delay is more than the threshold, skip the iteration.
float distanceSmoothFactor = 0.1; // Smoothing factor for distance readings (0 < alpha <= 1; lower values are smoother but slower to converge).

float leadingTurningCoefficient = 10;
float tailingTurningCoefficient = 0.5;


//
//
//////////////////////////////////////////////////////////////////////////////////

void setup() {
  // Start Serial for debugging
  unsigned long startTime = millis();
  unsigned long timeout = 1000; // 1 seconds timeout

  Serial.begin(115200);
  while (!Serial && (millis() - startTime < timeout)) {
    // Wait for Serial or timeout
  }

  establishAutocamRemoteBLEConnection();
  establishAutocamSensorBLEConnection();
  setupLED();
  setupESC();
  setupServer();
  setupBLECentral();
}

void loop() {
  // Initialize the periodic timing. These static variables keep their value between iterations.
  static TickType_t xLastWakeTime = xTaskGetTickCount();
  static TickType_t previousIteration = xLastWakeTime;

  // Calculate and print the interval between iterations.
  TickType_t currentIteration = xTaskGetTickCount();
  uint32_t intervalMs = (currentIteration - previousIteration) * portTICK_PERIOD_MS;
  previousIteration = currentIteration;
  //LOGF("Interval since last iteration: %u ms\n", intervalMs);

  attemptConnectRemote();
  attemptConnectSensor();
  //yield();

  getAutocamSensorData();
  getAutocamRemoteData();
  //yield();

  //printGlobalState();

  sendGimbalControllerData();
  updateAutocamRemoteStatus();
  //yield();

  calculateCoordinates();
  calculateSteeringThrottle();
  //yield();

  runESCController();
  checkDriveModeLED();
  runHealthCheck();
  //yield();

  // Delay until the next period; this call ensures a steady 10 ms loop period.
  vTaskDelayUntil(&xLastWakeTime, pdMS_TO_TICKS(LOOP_PERIOD_MS));
}

void setupLED() {
  ledController.initSensorLED(SENSOR_LED_RED_PIN, SENSOR_LED_GREEN_PIN, SENSOR_LED_BLUE_PIN);
  ledController.initRemoteLED(REMOTE_LED_RED_PIN, REMOTE_LED_GREEN_PIN, REMOTE_LED_BLUE_PIN);
  ledController.initDriveLED(DRIVE_MODE_LED_RED_PIN, DRIVE_MODE_LED_GREEN_PIN, DRIVE_MODE_LED_BLUE_PIN);

  ledController.updateStateLED(globalState.state);
  ledController.updateDriveModeLED(globalState.driveMode);
}

void setupESC() {
  LOGLN("Initializing ESC...");
  delay(1000); // Wait 1 seconds to ensure the ESC ready to arm.

  // Setup PWM
  ledcSetup(THROTTLE_PWM_CHANNEL, PWM_FREQ, PWM_RESOLUTION);
  ledcAttachPin(THROTTLE_PIN, THROTTLE_PWM_CHANNEL);

  ledcSetup(STEERING_PWM_CHANNEL, PWM_FREQ, PWM_RESOLUTION);
  ledcAttachPin(STEERING_PIN, STEERING_PWM_CHANNEL);

  // Send neutral signals
  setThrottle(midThrottle);
  setSteering(midSteering);

  LOGLN("ESC Initialized!");
}

// WiFi, WebServer, and WebSocket setup
void setupServer() {
  // Start Access Point
  WiFi.softAP(ssid, password);
  LOGLN("Access Point started!");
  LOG("SSID: ");
  LOGLN(ssid);
  LOG("IP Address: ");
  LOGLN(WiFi.softAPIP());

  // Start mDNS
  if (!MDNS.begin(hostname)) {
    LOGLN("Error starting mDNS");
    return;
  }
  LOGLN("mDNS responder started!");
  LOG("Access the device at http://");
  LOG(hostname);
  LOGLN(".local");

  // Configure WebSocket events
  ws.onEvent(onWebSocketEvent);
  server.addHandler(&ws);

  // Serve static files
  server.on("/", HTTP_GET, [](AsyncWebServerRequest *request) {
    request->send(200, "text/html", index_html);
  });

  // Add a new handler for serving the parameters page
  server.on("/parameters", HTTP_GET, [](AsyncWebServerRequest *request) {
    request->send(200, "text/html", parameters_page_html);
  });

  server.on("/get_parameters", HTTP_GET, [](AsyncWebServerRequest *request) {
    String json = "{";
    json += "\"distanceDelta\":" + String(distanceDelta, 2) + ",";
    json += "\"headingDelta\":" + String(headingDelta, 0) + ",";
    json += "\"cinemaLeadingHeadingDelta\":" + String(cinemaLeadingHeadingDelta, 2) + ",";
    json += "\"maxIntegralLimit_t\":" + String(maxIntegralLimit_t, 2) + ",";
    json += "\"maxIntegralLimit_s\":" + String(maxIntegralLimit_s, 2) + ",";
    json += "\"Kp_t\":" + String(Kp_t, 2) + ",";
    json += "\"Ki_t\":" + String(Ki_t, 2) + ",";
    json += "\"Kd_t\":" + String(Kd_t, 2) + ",";
    json += "\"Kp_s\":" + String(Kp_s, 2) + ",";
    json += "\"Ki_s\":" + String(Ki_s, 2) + ",";
    json += "\"Kd_s\":" + String(Kd_s, 2) + ",";
    json += "\"maxMoveThrottle\":" + String(maxMoveThrottle - midThrottle) + ",";
    json += "\"minMoveThrottle\":" + String(minMoveThrottle - midThrottle) + ",";
    json += "\"maxMoveSteering\":" + String(maxMoveSteering - midSteering) + ",";
    json += "\"minMoveSteering\":" + String(minMoveSteering - midSteering) + ",";
    json += "\"distanceSmoothFactor\":" + String(distanceSmoothFactor, 2);
    json += "}";
    request->send(200, "application/json", json);
    LOGF("get_parameters: %s\n", json.c_str());
  });

  // Add a handler to process the parameters update
  server.on("/update_parameters", HTTP_POST, [](AsyncWebServerRequest *request) {
    if (request->hasParam("distanceDelta", true)) {
      distanceDelta = constrain(request->getParam("distanceDelta", true)->value().toFloat(), 0, 5);
      LOGF("distanceDelta: %f\n", distanceDelta);
    }
    if (request->hasParam("headingDelta", true)) {
      headingDelta = constrain(request->getParam("headingDelta", true)->value().toFloat(), 0, 30);
      LOGF("headingDelta: %f\n", headingDelta);
    }
    if (request->hasParam("cinemaLeadingHeadingDelta", true)) {
      cinemaLeadingHeadingDelta = constrain(request->getParam("cinemaLeadingHeadingDelta", true)->value().toFloat(), 0, 5);
      LOGF("cinemaLeadingHeadingDelta: %f\n", cinemaLeadingHeadingDelta);
    }
    if (request->hasParam("maxIntegralLimit_t", true)) {
      maxIntegralLimit_t = constrain(request->getParam("maxIntegralLimit_t", true)->value().toFloat(), 0, 100);
      LOGF("maxIntegralLimit_t: %f\n", maxIntegralLimit_t);
    }
    if (request->hasParam("maxIntegralLimit_s", true)) {
      maxIntegralLimit_s = constrain(request->getParam("maxIntegralLimit_s", true)->value().toFloat(), 0, 100);
      LOGF("maxIntegralLimit_s: %f\n", maxIntegralLimit_s);
    }
    if (request->hasParam("Kp_t", true)) {
      Kp_t = constrain(request->getParam("Kp_t", true)->value().toFloat(), 0, 10);
      LOGF("Kp_t: %f\n", Kp_t);
    }
    if (request->hasParam("Ki_t", true)) {
      Ki_t = constrain(request->getParam("Ki_t", true)->value().toFloat(), 0, 10);
      LOGF("Ki_t: %f\n", Ki_t);
    }
    if (request->hasParam("Kd_t", true)) {
      Kd_t = constrain(request->getParam("Kd_t", true)->value().toFloat(), 0, 10);
      LOGF("Kd_t: %f\n", Kd_t);
    }
    if (request->hasParam("Kp_s", true)) {
      Kp_s = constrain(request->getParam("Kp_s", true)->value().toFloat(), 0, 10);
      LOGF("Kp_s: %f\n", Kp_s);
    }
    if (request->hasParam("Ki_s", true)) {
      Ki_s = constrain(request->getParam("Ki_s", true)->value().toFloat(), 0, 10);
      LOGF("Ki_s: %f\n", Ki_s);
    }
    if (request->hasParam("Kd_s", true)) {
      Kd_s = constrain(request->getParam("Kd_s", true)->value().toFloat(), 0, 10);
      LOGF("Kd_s: %f\n", Kd_s);
    }
    if (request->hasParam("maxMoveThrottle", true)) {
      maxMoveThrottle = midThrottle + constrain(request->getParam("maxMoveThrottle", true)->value().toFloat(), 0, 500);
      LOGF("maxMoveThrottle: %f\n", maxMoveThrottle);
    }
    if (request->hasParam("minMoveThrottle", true)) {
      minMoveThrottle = midThrottle + constrain(request->getParam("minMoveThrottle", true)->value().toFloat(), -500, 0);
      LOGF("minMoveThrottle: %f\n", minMoveThrottle);
    }
    if (request->hasParam("maxMoveSteering", true)) {
      maxMoveSteering = midSteering + constrain(request->getParam("maxMoveSteering", true)->value().toFloat(), 0, 500);
      LOGF("maxMoveSteering: %f\n", maxMoveSteering);
    }
    if (request->hasParam("minMoveSteering", true)) {
      minMoveSteering = midSteering + constrain(request->getParam("minMoveSteering", true)->value().toFloat(), -500, 0);
      LOGF("minMoveSteering: %f\n", minMoveSteering);
    }
    if (request->hasParam("distanceSmoothFactor", true)) {
      distanceSmoothFactor = constrain(request->getParam("distanceSmoothFactor", true)->value().toFloat(), 0.01, 1);
      LOGF("distanceSmoothFactor: %f\n", distanceSmoothFactor);
    }

    request->send(200, "text/plain", "Parameters updated");

    setDriveMode(DRIVE_MODE_MANUAL);
  });

  // Start server
  server.begin();
}

// Handle WebSocket events
void onWebSocketEvent(AsyncWebSocket *server, AsyncWebSocketClient *client,
                      AwsEventType type, void *arg, uint8_t *data, size_t len) {
  switch (type) {
    case WS_EVT_CONNECT:
      LOGLN("WebSocket connected");
      wsState = WEBSOCKET_CONNECTED;
      break;

    case WS_EVT_DISCONNECT:
      LOGLN("WebSocket disconnected");
      setDriveMode(DRIVE_MODE_MANUAL);
      LOGLN("Throttle and Steering reset to middle positions");
      wsState = WEBSOCKET_DISCONNECTED;
      break;

    case WS_EVT_DATA: {
      AwsFrameInfo *info = (AwsFrameInfo*)arg;

      // If this is the first fragment (index == 0), clear our buffer
      if (info->index == 0) {
        wsBuffer = "";
      }
      // Append this fragment’s payload
      wsBuffer += String((char*)data).substring(0, len);

      // If fin == true, this is the last fragment: process the full message
      if (info->final) {
        String message = wsBuffer;  // complete text

        // Reset the buffer for the next frame
        wsBuffer = "";

        // Now handle the full payload exactly once
        if (message == "REQUEST_DATA") {
          String response = "{";
          response += "\"throttle\":" + String(globalState.throttleValue) + ",";
          response += "\"steering\":" + String(globalState.steeringValue) + ",";
          response += "\"distance\":" + String(globalState.distance, 2) + ",";
          response += "\"heading\":" + String(globalState.heading, 2) + ",";
          response += "\"currentX\":" + String(globalState.currentX, 2) + ",";
          response += "\"currentY\":" + String(globalState.currentY, 2 ) + ",";
          response += "\"targetX\":" + String(globalState.targetX, 2) + ",";
          response += "\"targetY\":" + String(globalState.targetY, 2) + ",";
          response += "\"state\":" + String(globalState.state) + ",";
          response += "\"driveMode\":" + String(globalState.driveMode);
          response += "}";

          client->text(response);
        }
        else if (message == "driveMode=0") {
          setDriveMode(DRIVE_MODE_MANUAL);
        }
        else if (message == "driveMode=1") {
          setDriveMode(DRIVE_MODE_FOLLOW);
        }
        else if (message == "driveMode=2") {
          setDriveMode(DRIVE_MODE_CINEMA);
        }
        else if (message.startsWith("throttle=")) {
          globalState.throttleValue = map(
            message.substring(9).toInt(),
            1000, 2000,
            minMoveThrottle, maxMoveThrottle
          );
        }
        else if (message.startsWith("steering=")) {
          globalState.steeringValue = map(
            message.substring(9).toInt(),
            1000, 2000,
            minMoveSteering, maxMoveSteering
          );
        }
        else {
          LOGF("Unknown Websocket message: %s\n", message);
        }
      }
      break;
    }

    case WS_EVT_ERROR:
      LOGLN("WebSocket error");
      break;

    default:
      LOGLN("Unknown WebSocket event");
      break;
  }
}

void setThrottle(int microseconds) {
  uint32_t duty = microseconds * ((1 << PWM_RESOLUTION) - 1) / 20000;
  ledcWrite(THROTTLE_PWM_CHANNEL, duty);
}

void setSteering(int microseconds) {
  uint32_t duty = microseconds * ((1 << PWM_RESOLUTION) - 1) / 20000;
  ledcWrite(STEERING_PWM_CHANNEL, duty);
}

void runESCController() {
  setThrottle(globalState.throttleValue);
  if (abs(globalState.throttleValue - midThrottle) > minSteeringThrottle) { // Prevent dry (stationary) steering: only drive steering when throttle exceeds a minimum value.
    setSteering(globalState.steeringValue);
  }

  /*LOG("Throttle: ");
  LOG(globalState.throttleValue);
  LOG(" | ");
  LOG("Steering: ");
  LOGLN(globalState.steeringValue);*/
}

void runHealthCheck() {
  unsigned long now;

  // ----- Sensor health -----
  now = millis();
  if ((AutocamSensor.connected() && sensorState == BLE_CONNECTED && now - lastSensorConnectedTime > CONNECT_GRACE_MS && now - lastSensorDataMillis > sensorHeartbeatTimeout) || (!AutocamSensor.connected() && sensorState != BLE_SCANNING)) {
    LOGF("Sensor disconnected → restarting non‐blocking scan, now: %ld, lastSensorConnectedTime: %ld, lastSensorDataMillis: %ld\n", now, lastSensorConnectedTime, lastSensorDataMillis);
    disconnectPeripheral(AutocamSensor, AutocamSensorServiceUUID);
    sensorState = BLE_IDLE;
    emergencyStop();
    updateState(globalState.state & ~SERVER_STATE_SENSOR_CONNECTED & ~SERVER_STATE_SENSOR_READY);
    establishAutocamSensorBLEConnection();
  }

  // ----- Remote health -----
  //LOGF("now: %ld, lastRemoteDataMillis: %ld\n", now, lastRemoteDataMillis);
  if ((AutocamRemote.connected() && remoteState == BLE_CONNECTED && now - lastRemoteConnectedTime > CONNECT_GRACE_MS && now - lastRemoteDataMillis > remoteHeartbeatTimeout) || (!AutocamRemote.connected() && remoteState != BLE_SCANNING)) {
    LOGF("Remote disconnected → restarting non‐blocking scan, now: %ld, lastRemoteConnectedTime: %ld, lastRemoteDataMillis: %ld\n", now, lastRemoteConnectedTime, lastRemoteDataMillis);
    disconnectPeripheral(AutocamRemote, AutocamRemoteServiceUUID);
    remoteState = BLE_IDLE;
    emergencyStop();
    updateState(globalState.state & ~SERVER_STATE_REMOTE_CONNECTED & ~SERVER_STATE_REMOTE_READY);
    establishAutocamRemoteBLEConnection();
  }

  // ----- WebSocket health -----
  //now = millis();
  //if (wsState == WEBSOCKET_CONNECTED && now - lastWebSocketDataMillis > heartbeatTimeout) {
  //  LOGLN("WebSocket inactive → closing all clients");
  //  ws.closeAll();                     // Close every WebSocket client
  //  wsState = WEBSOCKET_DISCONNECTED;
  //}
}

void runSafetyCheck() {
  if (globalState.distance >= SAFETY_DISTANCE) {
    emergencyStop();
  }
}

void establishAutocamRemoteBLEConnection() {
  // Reset the flags and enter SCANNING mode
  remoteSendReady  = false;
  remoteRecvReady  = false;
  remoteState      = BLE_SCANNING;
}

void establishAutocamSensorBLEConnection() {
  sensorSendReady  = false;
  sensorRecvReady  = false;
  sensorState      = BLE_SCANNING;
}
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

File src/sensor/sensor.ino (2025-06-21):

#include <SPI.h>

#include "DW1000Ranging.h"
#include "DW1000.h"
#include "DJI_ronin_controller.hpp"
#include "BLE_setup.hpp"
#include "util.h"

// SPI pins
#define SPI_SCK 18
#define SPI_MISO 19
#define SPI_MOSI 23
#define DW_CS 4

// DW1000 pins
#define PIN_RST 27 // reset pin
#define PIN_IRQ 34 // irq pin
#define PIN_SS 4   // spi select pin

// DJI Can pins
#define CAN_TX 5  // Connects to CTX
#define CAN_RX 16  // Connects to CRX
#define CAN_RATE 1000 // Speed rate in kbps

#define SERVER_LED_RED_PIN 25
#define SERVER_LED_GREEN_PIN 26
#define SERVER_LED_BLUE_PIN -1
#define TAG_LED_RED_PIN 32
#define TAG_LED_GREEN_PIN 33
#define TAG_LED_BLUE_PIN -1

// leftmost two bytes below will become the "short address"
char uwbAddr[] = "AA:AA:6F:BE:08:3D:4E:72";

struct Anchor {
  uint16_t address;
  bool connected;
};

Anchor uwbAnchors[] = {
  {0x0000, false}, // NOTE(yifan): Make the UWB short address same as the index, for quick looking up.
  {0x0001, false},
  {0x0002, false}
};

uint8_t uwbSelector = 0;

// TAG antenna delay defaults to 16384
uint16_t Adelay = 16384;

float distance = 0;
float heading = 0;
uint8_t state = SENSOR_STATE_NOT_READY;
float yawSpeed = 0;
float pitchSpeed = 0;

uint8_t toggleState = NO_GIMBAL_TOGGLE;

DJIRoninController djiRoninController(CAN_TX, CAN_RX, CAN_RATE);

unsigned int lastPingTime = 0;

void setup() {
  // Start Serial for debugging
  unsigned long startTime = millis();
  unsigned long timeout = 1000; // 1 seconds timeout
                                //
  Serial.begin(115200);
  while (!Serial && (millis() - startTime < timeout)) {
    // Wait for Serial or timeout
  }

  delay(10000); // XXX(yifan): This is to compensate the DJI start-up. Looks like if we don't wait long enough, we can't get heading readings.
  setupLED();
  setupUWB();
  setupDJIRoninController();
  setupBLE();
  setupPinnedTask();
}

void setupPinnedTask() {
  // Create a task and pin it to core 0.
  // Parameters: task function, name, stack size, parameter, priority, task handle, core id.
  xTaskCreatePinnedToCore(
    nonUWBTask,   // Task function.
    "nonUWBTask", // Name of task.
    4096,         // Stack size in words.
    NULL,         // Task input parameter.
    1,            // Task priority.
    NULL,         // Task handle.
    0             // Core where the task should run (0 or 1).
  );
}

// Task function for non UWB computation that's not time critical.
void nonUWBTask(void * parameter) {
  // Set up the periodic timing
  TickType_t xLastWakeTime = xTaskGetTickCount();
  // Store previous iteration time
  TickType_t previousIteration = xLastWakeTime;

  while (true) {
    // Get the current tick count at the beginning of the iteration
    TickType_t currentIteration = xTaskGetTickCount();
    // Calculate the elapsed time in ticks and convert to milliseconds
    uint32_t intervalMs = (currentIteration - previousIteration) * portTICK_PERIOD_MS;
    previousIteration = currentIteration;
    //LOGF("Interval since last iteration: %u ms\n", intervalMs);

    if (getHeading()) {
      sendSensorDataSend();
    }
    getSensorDataRecv();
    applyUWBSelector();
    setGimbalPosition();
    checkGimbalToggleState();

    vTaskDelay(pdMS_TO_TICKS(LOOP_PERIOD_MS));
  }
}

void loop() {
  getDistance();
}

void setupLED() {
  pinMode(TAG_LED_RED_PIN, OUTPUT);
  pinMode(TAG_LED_GREEN_PIN, OUTPUT);
  pinMode(SERVER_LED_RED_PIN, OUTPUT);
  pinMode(SERVER_LED_GREEN_PIN, OUTPUT);
  digitalWrite(TAG_LED_RED_PIN, HIGH);
  digitalWrite(TAG_LED_GREEN_PIN, HIGH);
  digitalWrite(SERVER_LED_RED_PIN, HIGH);
  digitalWrite(SERVER_LED_GREEN_PIN, HIGH);

  updateLED(state);
}

void setupBLE() {
  AutocamSensorService.addCharacteristic(AutocamSensorDataSend);
  AutocamSensorService.addCharacteristic(AutocamSensorDataRecv);
  setupBLEPeripheral("Autocam Sensor", "autocam-sensor", AutocamSensorService);
}

void setupUWB() {
  //init the configuration
  SPI.begin(SPI_SCK, SPI_MISO, SPI_MOSI);
  DW1000Ranging.initCommunication(PIN_RST, PIN_SS, PIN_IRQ); //Reset, CS, IRQ pin

  // set antenna delay for anchors only. Tag is default (16384)
  //DW1000.setAntennaDelay(Adelay);

  DW1000Ranging.attachNewRange(newRange);
  DW1000Ranging.attachNewDevice(newDevice);
  DW1000Ranging.attachInactiveDevice(inactiveDevice);

  // NOTE (yifan): The DW1000 "tag" is different from the Autocam "tag".
  // In fact, the naming conventions are reversed:
  //   - DW1000 "anchors" correspond to Autocam Remote and Autocam Tag.
  //   - DW1000 "tag" corresponds to sensor.
  // This reversal is due to the DW1000 library's limitation of supporting a single tag with multiple anchors,
  // whereas our system uses multiple anchors (Autocam Remote and Autocam Tag).
  DW1000Ranging.startAsTag(uwbAddr, DW1000.MODE_LONGDATA_RANGE_LOWPOWER, false);
}

void getSensorDataRecv() {
  if (!(BLECentral && BLECentral.connected())) {
    if (!connectToCentral()) {
      resetGimbalControl();
      return;
    }
  }
  updateState(state | SENSOR_STATE_SERVER_CONNECTED);

  if (!AutocamSensorDataRecv.written()) {
    return;
  }

  // TODO(yifan): Maybe verify the input.
  SensorDataRecv data;
  AutocamSensorDataRecv.readValue((uint8_t *)&data, sizeof(SensorDataRecv));
  //LOGF("Received yawSpeed=%f, pitchSpeed=%f, toggleState=%d, uwbSelector=%d\n", data.yawSpeed, data.pitchSpeed, data.toggleState, data.uwbSelector);
  yawSpeed = data.yawSpeed;
  pitchSpeed = data.pitchSpeed;
  toggleState = data.toggleState;
  uwbSelector = data.uwbSelector;

  //LOGF("Data interval: %d(ms)\n", millis() - lastPingTime);
  lastPingTime = millis();
}

void setGimbalPosition() {
  float yaw = convert_gimbal_speed(yawSpeed);
  float pitch = convert_gimbal_speed(pitchSpeed);
  if (!djiRoninController.set_position(yaw, 0, pitch, 0, 100)) {
    LOGLN("Failed to set DJI Ronin position");
  }
}

void checkGimbalToggleState() {
  switch (toggleState) {
    case NO_GIMBAL_TOGGLE:
      break;
    case ACTIVE_TRACK_TOGGLED:
      toggleActiveTrack();
      break;
    case GIMBAL_RECENTER_TOGGLED:
      triggerGimbalRecenter();
      break;
    case CAMERA_RECORDING_TOGGLED:
      toggleCameraRecording();
      break;
    default:
      LOGF("Unknown toggle state %d\n", toggleState);
  }
  toggleState = NO_GIMBAL_TOGGLE;
}

void toggleActiveTrack() {
  if (!djiRoninController.gimbal_active_track()) {
    LOGLN("Failed to trigger DJI Ronin active track");
  }
}

void triggerGimbalRecenter() {
  if (!djiRoninController.gimbal_recenter()) {
    LOGLN("Failed to trigger DJI Ronin gimbal recenter");
  }
}
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

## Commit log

2024-12-31 ESP32_webserver: Fix wrong data field names for distance and heading.
2024-12-31 ESP32_webserver_ecs_controller: Fix turning bug.
    Previously, when the target moves from negative heading towards positive
    heading, the headingDiff is not continuous, causing sudden turning jump.
    This fixes the issue by moving the turning point to the 180 degree
    position (the back).
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2025-01-20 ESP32_can_controller: Fix last frame determination in recv_data().
    Also add _execute_command() to refactor the duplicated code.
2025-01-23 *: Add dji remote controller:
    Remote controller (peripheral) ===BLE==> server (central)
    Server (peripheral) ===BLE==> sensor, previously anchor (central)
2025-01-26 *: Only use server as central.
    There's some issue with multiple read/write characteristics on a single
    service. And also an issue with struct size that's 24, but strangerly
    the issue doesn't show up when the size is 28. Maybe some fragmentation
    issue.
    So keep the struct that's 28, and split the one that's 24 into two
    struct one for read one for write.
    It seems to be stable now, I can review this later if that's necessary.
    [remote_controller.ino, sensor.ino, server.ino]
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2025-02-23 LED_controller: Add LED for server and sensor.
    Also refactor the LED_controller lib.
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2025-03-02 hardware: Add sensor pcb.
    [sensor-B_Cu.gbl, sensor-B_Cu.gbr, sensor-B_Mask.gbr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]
2025-03-02 KiCad footprint library: Refactor footprint names.
    [sensor-B_Cu.gbl, sensor-B_Mask.gbs, sensor-B_Paste.gbp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]
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2025-03-02 hardware/server: Add server PCB.
    [sensor-B_Cu.gbl, sensor-B_Mask.gbs, sensor-B_Silkscreen.gbo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]
2025-03-02 hardware/tag: Add Autocam Tag PCB.
    [sensor-B_Cu.gbl, sensor-B_Mask.gbs, sensor-B_Paste.gbp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]
2025-03-03 hardware: Add more footprint measurement.
    [remote.kicad_pcb, remote.kicad_sch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]
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2025-03-07 hardware: Add remote PCB.
    [remote-B_Cu.gbl, remote-B_Mask.gbs, remote-B_Paste.gbp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]
2025-03-07 hardware/remote: Minor update to make more clearance for the antenna
    [remote-B_Cu.gbl, remote-B_Mask.gbs, remote-B_Paste.gbp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]
2025-03-07 remote: Add battery status LED logic.
    [remote-B_Cu.gbl, remote-B_Mask.gbs, remote-B_Paste.gbp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]
2025-03-07 hardware/server: Update LED shape, change to all round LEDs.
    [server-B_Cu.gbl, server-B_Mask.gbs, server-B_Paste.gbp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]
2025-03-08 hardware/tag: Adjust signature position.
    [tag-B_Cu.gbl, tag-B_Mask.gbs, tag-B_Paste.gbp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]
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2025-03-08 hardware/tag: Remove the tag active led.
    The tag has not turned on the BLE yet.
    [tag-B_Cu.gbl, tag-B_Mask.gbs, tag-B_Paste.gbp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]
2025-03-08 remote: Add lock switch logic.
    When lock switched on on, no input will be read. But the previous input
    will not be cleared (means it can keep the previous throttle, steering values)
2025-03-08 hardware: Increase the LED resistor from 2000Ω to 10KΩ.
    To reduce the power consumption.
    [remote-B_Cu.gbl, remote-B_Mask.gbs, remote-B_Paste.gbp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]
2025-03-08 remote: Add UWB selector switch.
    This switch will choose whether to use tag or the remote for the
    distance measurement.
    Also updated the PIN number and moved all non-uwb task to a separate
    core.
    [remote.kicad_pcb, remote.kicad_sch]
2025-03-09 hardware: Reroute the wires to fix unavailable PINs.
    [remote-B_Cu.gbl, remote-B_Mask.gbs, remote-B_Paste.gbp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]
2025-03-09 hardware: Test all the input/output pins.
    [remote-B_Cu.gbl, remote-B_Mask.gbs, remote-B_Paste.gbp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]
2025-03-09 util: Add macro for Serial.printf.
    So that it can be turned off in production.
    Also renamed remote_controller to remote, and uwb_tag to tag to match
    the hardware folder.
2025-03-09 BLE_setup: Naming cleanups.
    Rename AutocamController to AutocamRemote.
    Rename UWBAnchor to AutocamSensor.
    Rename ControllerData to RemoteDataBidirection.
    Also cleaned up uwb tag/anchor names, instead of using uwb anchor/tag,
    call it Autocam Sensor(the uwb tag) and Autocam device (the uwb anchor,
    which is the Autocam Remote and Autocam Tag).
2025-03-09 remote/sensor: Apply data rate controlling logic.
    Use vTaskDelayUntil() ensures a steady 10 ms period between each
    iteration.
2025-03-09 hardware: Move the PCB to near the coordinate origin.
    [remote-B_Cu.gbl, remote-B_Mask.gbs, remote-B_Paste.gbp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]
2025-03-09 hardware: Move plot output to dedicated folders.
    [remote-B_Cu.gbl, remote-B_Mask.gbs, remote-B_Paste.gbp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]
2025-03-09 server: Disable auto pilot when switching the target uwb tag.
    This is to prevent from wrong distance / heading combination readings.
    Also update .gitignore to ignore zip files.
    [server.ino]
2025-03-09 hardware: Update pcd design for better wiring clearance.
    [remote-B_Cu.gbl, remote-B_Mask.gbs, remote-B_Paste.gbp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]
2025-03-10 hardware: Revise the drive mode naming.
    [remote-B_Cu.gbl, remote-B_Mask.gbs, remote-B_Paste.gbp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]
2025-03-10 server/remote: Remove auto pilot sub-mode, just add another major mode..
    Also update the UI:
    - WebUI: Use a 3-way switch to select between the modes. Also refactored
    the code a little bit.
    - Remote controller: Use single double and triple click to switch
    between different modes.
2025-03-10 hardware: Update remote gimbal fn button naming.
    [remote-B_Cu.gbl, remote-B_Mask.gbs, remote-B_Paste.gbp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]
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2025-03-19 hardware: Add cad folder for the enclosure. Update pcb wiring for v2.
    Update the PCB wiring and mounting holes after receiving the first batch
    of PCB.
    [Sensor Assembly.FCStd, Sensor Base.FCStd, Sensor Lid.FCStd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]
2025-03-26 *: Update after the first PCB assembly.
    - Replaced the 200k ohm resistor with 100k ohm on tag_v2, as GPIO pin 32
    reduces the voltage somehow, updated the battery voltage divider
    accordingly in tag.ino
    - Fix an issue of tag LED as the tag will not invoke newDevice() even
    though it's added by the Sensor.
    - Updated the DRIVE_MODE_MANUAL to be long steady light instead of
    blincking.
    - Fixed a short wiring issue on the sensor.
    [Sensor Assembly.FCStd, Sensor Base.FCStd, Sensor Lid.FCStd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]
2025-03-27 remote: Update PCB for remote.
    Fix the issue that GPIO 35 does not have internal PULLUP resistor.
    So switch the pin with the gimbal thumbstick input Y, instead of the
    drive mode button.
    Update sensor and tag pcb as well to reflect the changes.
    - tag: Use pin 39 for battery measurement and revert the resistor value
    change that's done in the previous commit.
    - sensor: Fix a wiring issue.
    [remote_v2-B_Cu.gbl, remote_v2-B_Mask.gbs, remote_v2-B_Paste.gbp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]
2025-03-27 sensor,tag: Update PCB wiring to avoid bootstrap pins.
    [sensor-B_Cu.gbl, sensor-B_Mask.gbs, sensor-B_Paste.gbp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]
2025-03-28 remote: Calibrate the joystick, fix drive mode button issue.
    [remote.ino, server.ino, tag.ino]
2025-03-31 hardware/cad: Finish sensor and server enclosure.
    [Sensor Assembly.FCStd, Sensor Base.FCStd, Sensor Lid.FCStd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]
2025-04-16 hardware/cad: Add remote and tag enclosure.
    [Remote Assembly.FCStd, Remote Base.FCStd, Remote Lid.FCStd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]
2025-04-16 hardware/cad/server: Update server enclosure.
    [Server Assembly.FCStd, Server Base.FCStd, Server Lid.FCStd]
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2025-04-22 hardware/cad/*: Add 3mf files for 3d-print, update model.
    Add mounting screw holes for the tag and remote.
    Update mounting screw holes for the sensor base.
    Adjust height.
    [Remote Assembly.FCStd, Remote Base-Base.3mf, Remote Base.FCStd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]
2025-05-16 hardware/tag: Update tag pcb to fix the mirror error.
    Previous version does not include the hole.
    [Tag Assembly.FCStd, Tag Base.FCStd, Tag Lid.FCStd]
2025-05-17 src/server: Replace ESP32servo with ledcWrite.
    This is a workaroud for pin A5 A6 to support pwm.
    [server.ino]
2025-05-17 src/remote: Fix a pullup setup for the drive mode button.
    [remote.ino]
2025-05-22 src/server: Update server throttle and steering pins.
    - Revert to using the ESP32Servo lib.
    - Update the pin numbers.
    [server.ino]
2025-05-22 hardware/pcb/server: Update pcb pins for the server.
    Update the wiring accordingly to use D2-D8 pins.
    [server-B_Cu.gbl, server-B_Mask.gbs, server-B_Paste.gbp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]
2025-05-31 src/*: Multiple changes.
    server: Move current and target coordinates to the globalState.
    sensor: Fix an issue where the sensor gets wrong heading values from the
    DJI CAN if it starts too early.
    remote: Use the remote as the default uwb tag. Adjust throttle and
    gimbal speed, reverse the gimbal control.
    [remote.ino, sensor.ino, server.ino]
2025-05-31 src/server, remote: Split AutocamSensorDataBidirection
    This fixes an issue where the server could read empty throttle/steering
    values if it writes to the same characteristic as a status report after
    reading it from the remote.
    [remote.ino, server.ino]
2025-05-31 src/server: Fix throttle issue, increase steering power.
    [server.ino]
2025-06-01 src/server: Fix parameter tuning page.
    [server.ino]
2025-06-02 src/sensor,remote: Fix an issue for remote.
    Previously, when pressing a button, it will not send the values to the
    server if the value are the same as before on the remote side. The
    change makes it to send the values anyway because sometimes the server
    could have different values (e.g. after parameter updates).
    [remote.ino, sensor.ino]
2025-06-03 src/server: Update PID control logic.
    Fix integral and deritive term calculation, add code to reset.
    [server.ino]
2025-06-03 src/server: Fix BLE connection bugs.
    Use a state machine to fix the heart timeout oscillation issue.
    Fix reconnection issue when previously the BLE device is not cleared
    before re-scanning.
    [server.ino]
2025-06-03 src/remote: Reset driveMode and gimbal toggle state when disconnected.
    [remote.ino]
2025-06-03 src/server: Fix follow mode throttle coeff calculation.
    [server.ino]
2025-06-03 src/server: Refactor the heartbeat logic.
    Seprate the websocket and sensor heartbeat, so when they timeouts,
    reconnect the websocket or the sensor respectively.
2025-06-03 src/server: Prevent dry steering.
    Also refine the state machine logic.
    [server.ino]
2025-06-04 src/remote, server: Refactor throttle mapping, remote signal drop.
    Also improved the webserver stabability by removing the healthcheck
    because we won't really use phone to control the car for now.
    [remote.ino, server.ino]
2025-06-06 hardware/*/tag: Update the 3mf file to fix the missing holes.`
    [Tag Lid-Lid.3mf]
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2025-06-07 src/*: Support multiple uwb selector and simplify the server relay logic
    Since in the remote we already prevent sending duplicated values, so the
    server can safely relay the remote input to the sensor.
    [sensor.ino, server.ino]
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2025-06-07 src,ios: Make sure the remote resets drive mode after a disconnection.
    [remote.ino]
2025-06-09 libraries/can_controller: Fail earlier after reading a wrong seq.
    This just makes the sensor the give up the current command earlier and
    prevents it from stuck in the loop for too long.
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2025-06-09 src/server: Increase the health check timeout.
    Increase stability.
    [server.ino]
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2025-06-12 src/server: Fix cinema mode turning error.
    [server.ino]
2025-06-12 src/server: Fix web ui throttle value
    [server.ino]
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
